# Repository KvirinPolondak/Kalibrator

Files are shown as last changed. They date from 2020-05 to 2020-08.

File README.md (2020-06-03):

# System for evaluating the color response of a digital camera sensor

A controllable light source comprising of a multiplicity of
light-emitting diodes and semiconductor lasers covering the visible
spectrum: from near infrared (1000 nm) to UVA (365 nm). The output
intensity of the diodes/lasers should be remotely controllable via USB
and/or BlueTooth. Demonstrate the use of the developed instrument to
evaluate the color gamut of at least one digital camera sensor.

# Sustav za evaluaciju odziva boje digitalne kamere

Izvor svjetla od više svjetlećih dioda i poluvodičkih lasera
koji pokrivaju vidljivi dio spektra: od 1000 nm (infracrvena boja) do
365 nm (ultraljubičasta boja A). Intenzitet svjetla iz svake diode će
se kontrolirati preko USB sučelja ili preko BlueTooth sučelja.
Demonstrirati korištenje razvijenog uređaja za mjerenje gamuta barem
jedne digitalne kamere.

## Complete documentation
https://github.com/KvirinPolondak/Kalibrator/blob/master/Dokumentacija/main_documentation.pdf

## Pictures
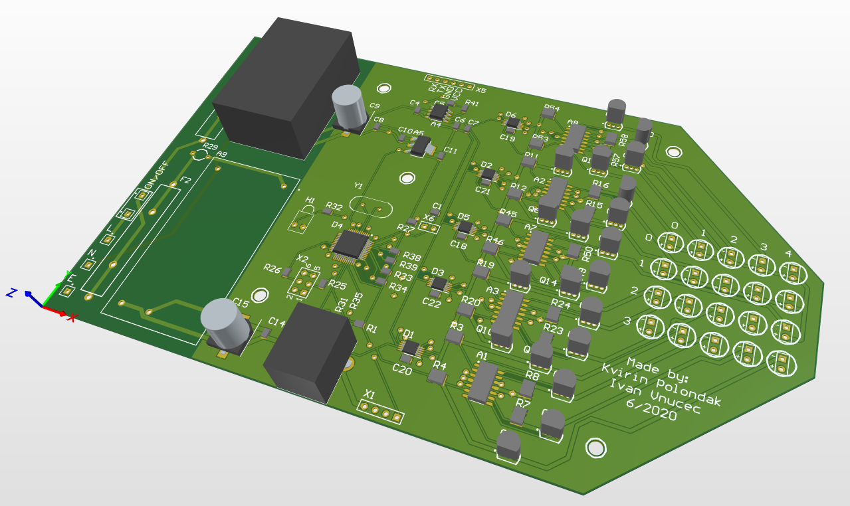
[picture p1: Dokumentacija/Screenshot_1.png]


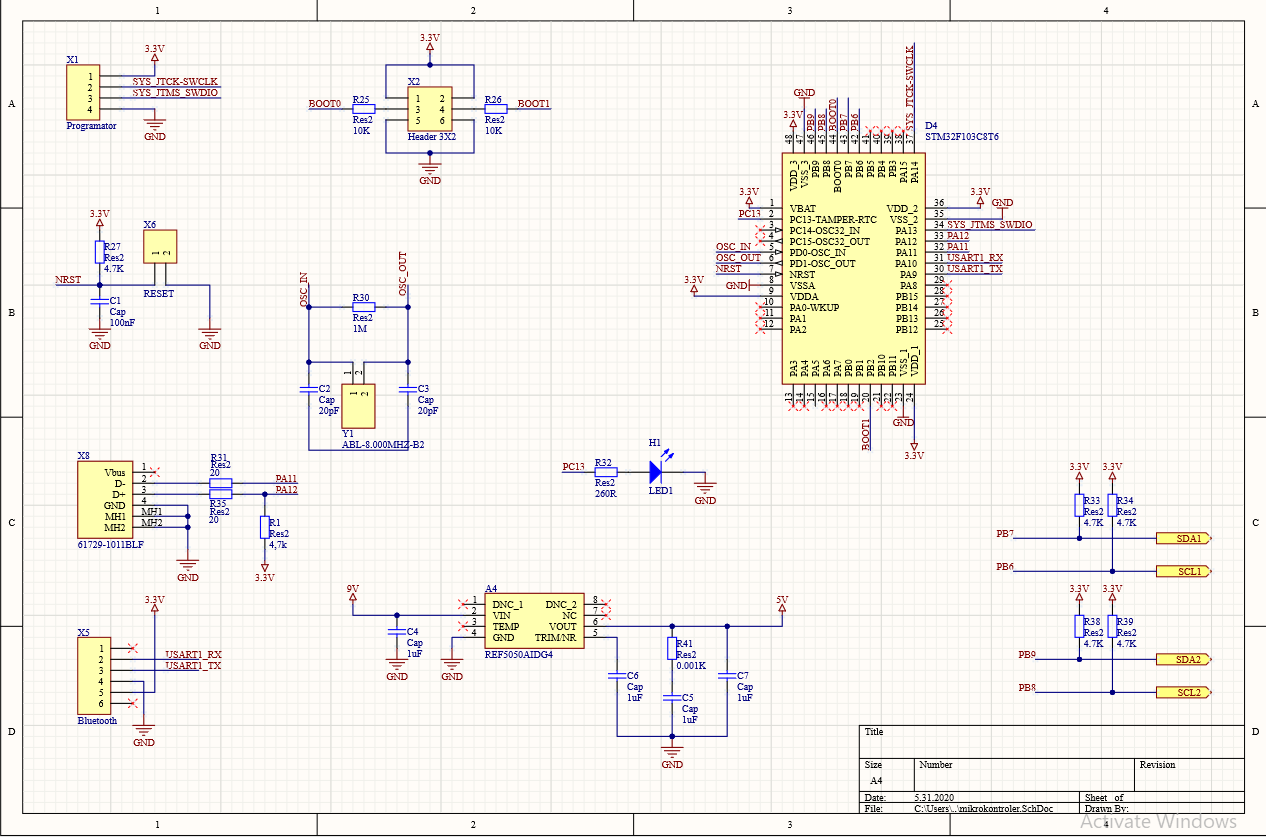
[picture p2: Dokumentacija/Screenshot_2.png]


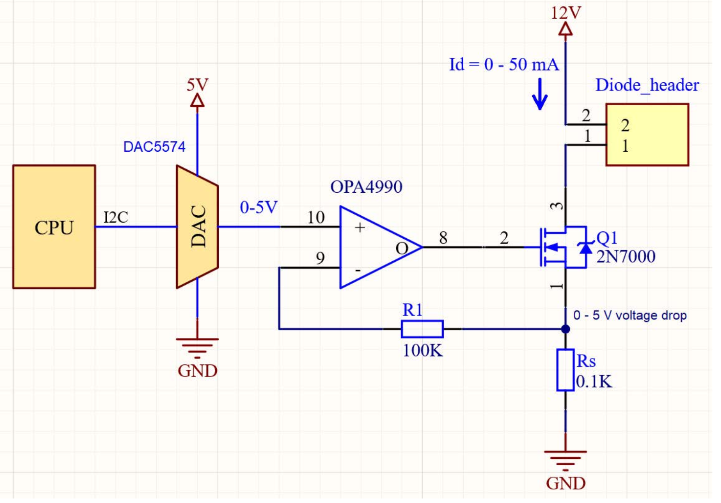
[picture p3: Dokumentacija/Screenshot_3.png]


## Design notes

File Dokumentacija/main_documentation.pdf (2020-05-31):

## Table of Contents

## Introduction

Our main goal is to distinguish various types of light sources based on their color gamut response. From the previous experiments where we had studied color gamut response from different kinds of lamps (LED, RGB LED, HPS, Fluorescent etc.) we hypothesized that we might determine the type of streetlamp only by looking at their color gamut.
Figure 1 portrays how certain kinds of lamps fall into their region and based on in what region they are in, we might decide their type.

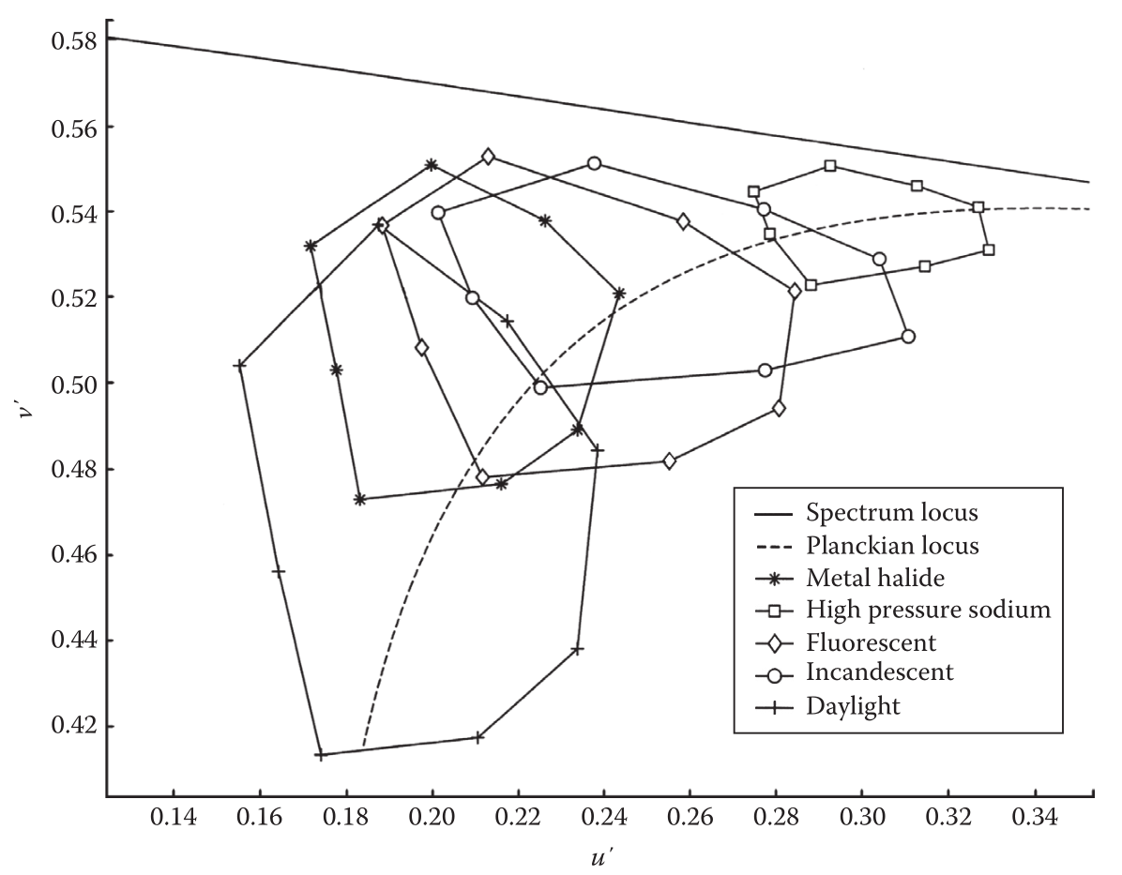
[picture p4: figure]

Figure 1 The color gamuts for high-pressure sodium (HPS), incandescent, fluorescent, and metal halide light sources, and for the CIE Standard Illuminant D65, simulating daylight, all plotted on the CIE 1976 UCS diagram. The dotted curve is the Planckian locus. (Boyce, 2014)

To test our hypothesis, firstly we would need to capture hundreds of responses from numerous light sources, which would be a tremendous job.

A method for capturing color gamut response is firstly capturing the radiating light from the light source with a digital camera and then calculate the so-called CIE chromaticity x and y and z coordinates based on the light source color. For the complete formulations, please see (Boyce, 2014).
We would like to have a device that contains numerous different monochromatic light sources. Device should turn every one of those light sources independently with user selectable light intensity.

## 1. Device

## 1.1. Requirements

Below is a list of requirements that the device must have:
- The device must contain an array of twenty two-leaded connectors to connect twenty different light sources (LEDs, Low-power lasers etc.).
- The device must have the ability to receive commands ether trough Universal Serial Bus (USB) or wirelessly with the Bluetooth protocol. Commands must be in a simple ASCII string form.
- Every command must specify what light source should be turned on and with what intensity.
- The board must be powered with conventional EU plug (230V, 60 Hz).

## 1.2. Principle of operation

Figure 2 portrays general functional block diagram. On the left side we have two communication ports: USB and Bluetooth. Both of those communication channels are bidirectional.
Between a communication ports and light-sources-array lays low-cost general-purpose microcontroller that acts as a bridge between the two. His function is to encode the user commands (which are human readable) into analog voltage and current that would drive each light-source.
Next to the microcontroller is light-source-array consisting of 20 different monochromatic light-sources. Every different light-source is physically swappable by the user.

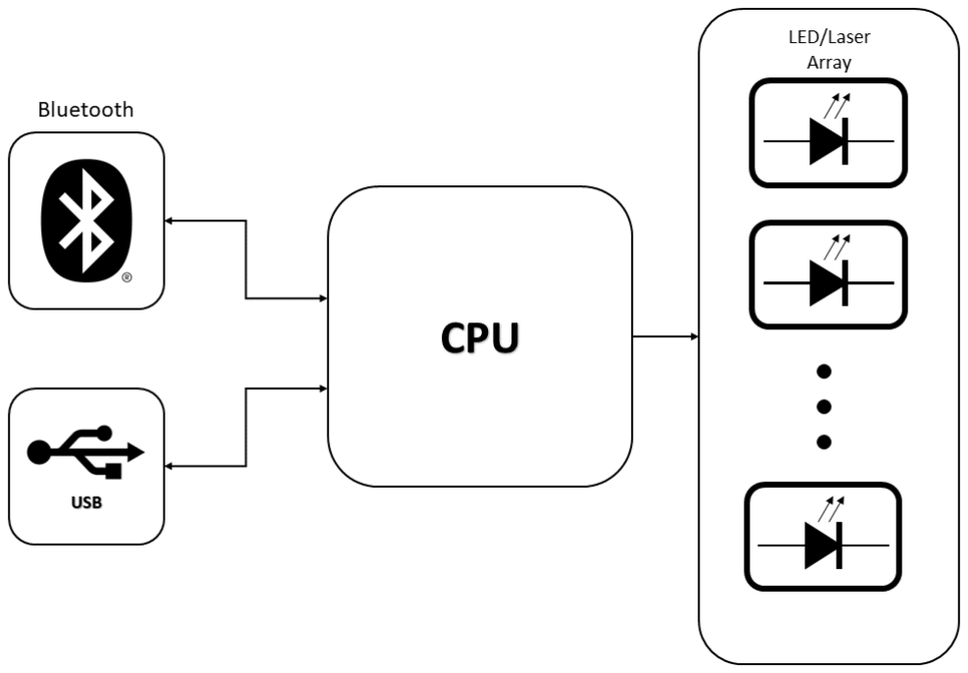
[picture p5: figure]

Figure 2 - Functional block diagram

### 1.2.1. Communication

### Bluetooth

Bluetooth stack and communication protocol is vast topic by its own. As a result, we have chosen a system-on-chip solution (SOC) Bluetooth module. The module has the advantage over other Bluetooth solutions because the communication between two Bluetooth nodes goes over a UART protocol with an ASCII coded characters as data.
We intend to use rather famous between hobbyists AT-09 module. Other modules could also be of good use as long as they have the simple UART interface.

### USB

For the USB side it is no different. Microcontroller has native support (both hardware and software) for USB communication. Data will be sent through established Virtual COM port emulation RS-232 serial communication in ASCII decoded characters.

### 1.2.2. CPU

For the CPU we chose general-purpose STM32F103 series microcontroller (MCU), which has all the functionalities we need: USB, USART, and two I²
C communication ports. Also, contains 64 KB Flash memory and 20 KB RAM, which is sufficient for our application (STMicroelectronics , 2020).

### Functionality

The MCU receives commands through USB or Bluetooth, encodes them, and then sends them to the Light source array over I²
C communication. The latter part is explained later in details.

### 1.2.3. Light-source array

### Overview

Figure 3 portrays the light-source array consisting of 20 independent LED or laser diodes where each light-source can be lit with its own amount of current.
The array consists of modules where every single module has analog circuitry that governs an amount of current and voltage of each diode.

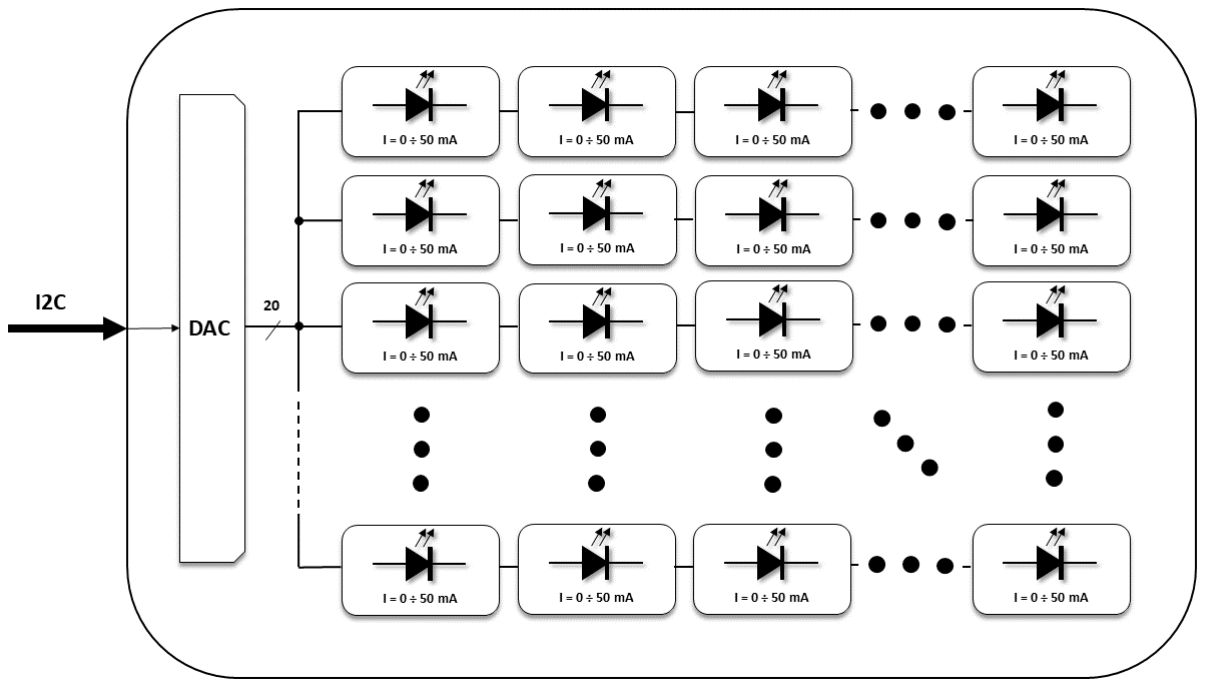
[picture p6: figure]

Figure 3 - Light-source array

Every cell consists of one Digital-to-analog converter (DAC), Operational amplifier (OP-AMP), MOSFET transistor, current-sense resistor, and one header connector for the diode (Figure 4).

### Principle of operation

Id is the desired current trough the diode ranging from 0 to 50 mA. This current creates voltage drop on the current-sense resistor Rs in the range from 0 to 5 volts. This voltage drop then goes to the OP-AMP which then compares the desired voltage (+ side) to the voltage drop across Rs resistor. The DAC output voltage ranges also from 0 to 5 volts. Based on the difference, OP-AMP drives the gate of the MOSFET which then regulates the current trough the diode by varying its drain-to-source voltage drop.

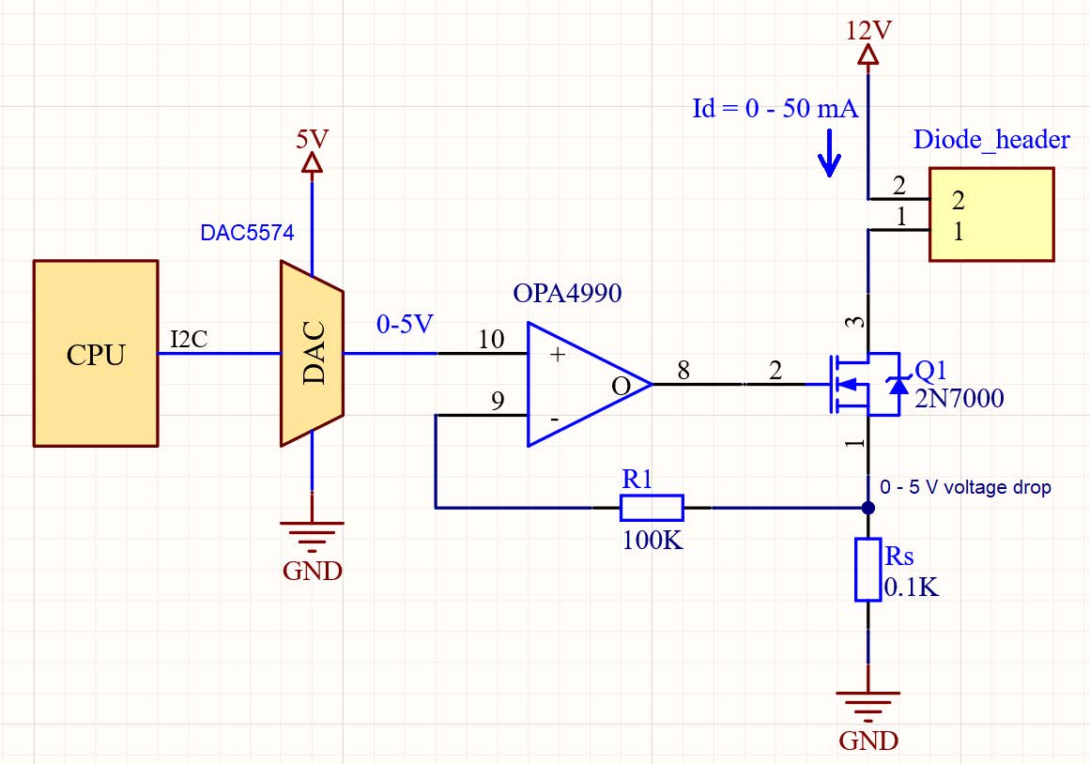
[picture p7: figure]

Figure 4 - Light-source array cell

DAC

The DAC5574 is a rail-to-rail, quad channel, 8-bit digital-to-analog converter (DAC) whose output voltage ranges from 0 to 5 volts. It consists of 4 DACs in one package in order to save printed-circuit board (PCB) space.

Least significant bit (LSB) of the DAC output is equivalent to:

# ULSB = Uout

# 2n_bits = 5 V

# 256 bit

≅ 19.531

mV
bit .

Communication with the DACs goes over an I

2
C interface.

OP-AMP

For the OP-AMP, we chose OPA4990 general-purpose operational amplifier with rail-torail input/output. It consists of 4 OP-AMPs in one package in order to save PCB space. The OP-AMP output is directly connected to a 2N7000 gate general-purpose, low-voltage, enhanced-mode MOSFET.
The OP-AMP short-circuit-input principle gives us the LSB diode current:

# Id,LSB = ULSB

Rs

≅

19.531 mV

### bit

100 Ω

≅ 0.1953

mA
bit .

Therefore, with the 8-bit DAC output we have 0-50 mA current swing.

MOSFET

General-purpose 2N7000 MOSFET drives its drain-to-source voltage drop in order to set a desired current trough the diode specified by the OP-AMP.
Because of the low power-loss across the transistor, we have chosen TO-92 package.

Power supply voltage

We chose 12 Volts as the power supply voltage because it covers wide forward-voltagedrop range.

## 2. Usage

This section describes general procedures of using the device.

## 2.1. Power

Power supply

In order to power up the device, user must plug in main power plug into 230 V, 50 Hz EU electrical socket and then turn on the main power switch.
If there are no errors, the status LED should be blinking and the light-source array is completely turned off.

Fuses

To prevent the device from permanent electric damage user must install two different fuses. To install fuses user should firstly power off the device by unplugging it from the electrical grid and then open the box.
Into designated fuse holders, install two types of fuses:
- Slow blow, 40 A, 250 V for 12 V rail and,
- Slow blow, 20 A, 250 V for 9 V rail.

## 2.2. Light-source array

In order to place individual light sources, firstly turn the device off. Next, put two leads into their appropriate header paying attention about leads polarity.
After plugging the device on, the light-source array is automatically entirely turned off.

## 2.3. Communication

### USB

In order to use USB communication, user should connect PC and a device with an USB 2.0 type B connector cable.
The device should appear on a PC as a virtual COM port. Communication with the device can be established via standard Serial port monitors.

### Bluetooth

To use Bluetooth communication user must firstly establish a connection between two Bluetooth devices. After that, user should use standard Serial port monitors. Serial port monitors exist for both PC and mobile phones.

### Commands

Commands could be sent using traditional Serial port monitors with a simple commands format explained below.

### Commands format

In order to address every single light source, we have developed a command format which every user must follow. The format is explained below:
D_XX_YY.ZZ
Where:
- “D” is an ASCII character abbreviating the word diode,
- “XX” is a leading zero, two digit, natural number (e.g., 00, 01, 02 , … , 98 ,
99) representing a diode ID and
- YY.ZZ is a leading zero, rational number (e.g., 00.00 , 00.01, … , 99.99) representing a current trough the light source in miliamperes (see Light-source array heading).
For example, if user wants to set a 3.52 mA current trough some arbitrary diode with an ID No. 7, user must send an ASCII command string:

D_07_03.52
Highest YY.ZZ diode current is 50.00 miliamperes by design. If user sends command with a higher current requirement, the command will be ignored. In order to turn off the diode, user should put 00.00 as the YY.ZZ value.
Diode ID numeration is shown in figure below. First ID (00) is in phisicly located in the upper-left corner. Next ID (01) is located next to it to the right side and so on.

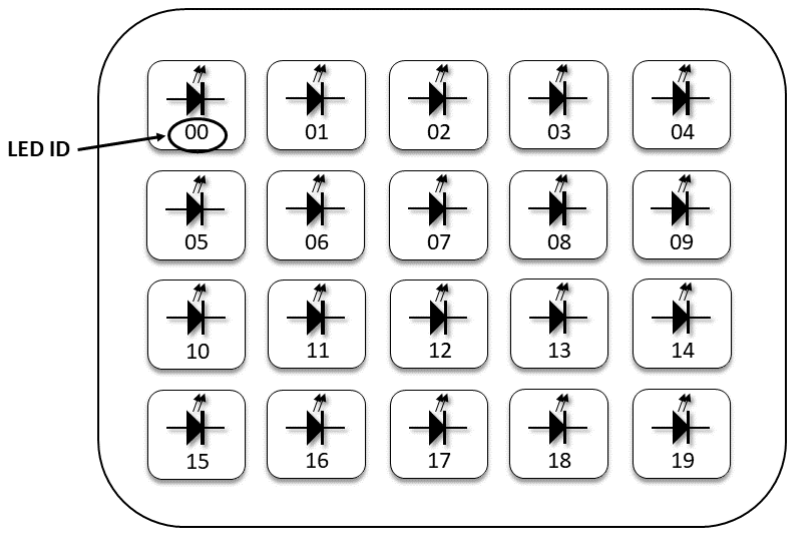
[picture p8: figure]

Figure 5 - Physical layout of the light-source array

## Conclusion

asdasdsd

## Literature

Boyce, P. R. (2014). Human Factors in Lighting. Boca Raton: CRC Press. STMicroelectronics . (7. May 2020). STMicroelectronics . Preuzeto 7. May 2020 iz Microcontrollers & Microprocessors: https://www.st.com/en/microcontrollersmicroprocessors/stm32f103.html
Texas Instruments. (n.d.). Product page. Preuzeto May 2020 iz DAC5574 product page: http://www.ti.com/product/DAC5574
Texas Instruments. (n.d.). Products. Preuzeto May 2020 iz OPA4990 product page: https://www.ti.com/product/OPA4990

## Abstract

System for evaluating the color response of a digital camera sensor
Build a controllable light source comprising of a multiplicity of light-emitting diodes and semiconductor lasers covering the visible spectrum: from near infrared (1000 nm) to UVA (365 nm). The output intensity of the diodes/lasers should be remotely controllable via USB and/or Bluetooth. Demonstrate the use of the developed instrument to evaluate the color gamut of at least one digital camera sensor.

## Sažetak (Croatian)

Sustav za evaluaciju odziva boje digitalne kamere
Izraditi izvor svjetla od više svjetlećih dioda i poluvodičkih lasera koji pokrivaju vidljivi dio spektra: od 1000 nm (infracrvena boja) do 365 nm (ultraljubičasta boja A). Intenzitet svjetla iz svake diode će se kontrolirati preko USB sučelja ili preko Bluetooth sučelja. Demonstrirati korištenje razvijenog uređaja za mjerenje gamuta barem jedne digitalne kamere.

## Keywords

Ovo poglavlje nije obavezno, ali se može dodati radi preglednosti.

ATM Asynchronous Transfer Mode | asinkroni način prijenosa
ISDN Integrated Services Digital Network | digitalna mreža integriranih usluga

Napomena: na naslov Skraćenice primijenite stil Heading 1, a zatim ručno maknite brojčanu oznaku (to je važno kako bi i skraćenice ušle u sadržaj na početku rada, prije uvoda). Pri kreiranju popisa skraćenica koristite stil nabrajanje.

## Appendix A: PCB documentation

## A.1 Schematic sheet documents

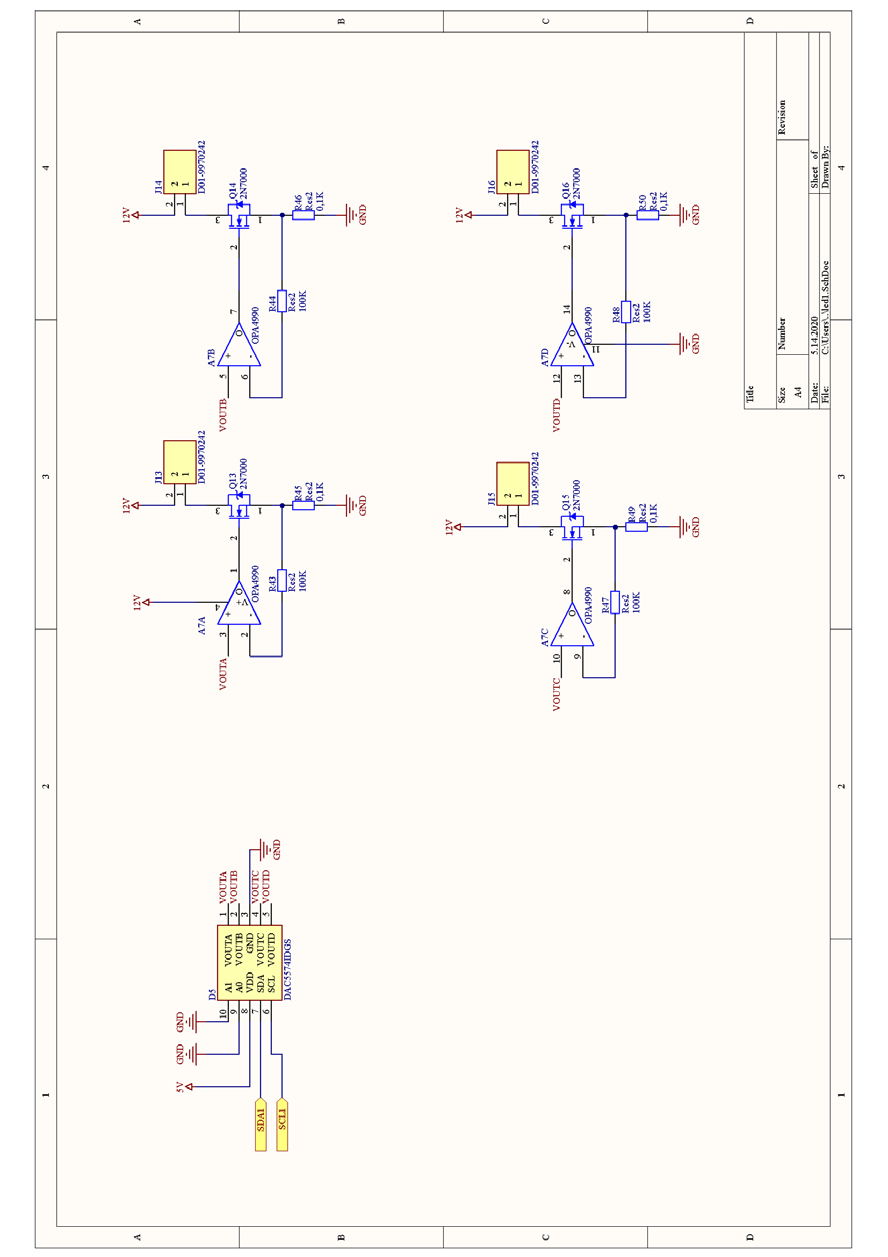
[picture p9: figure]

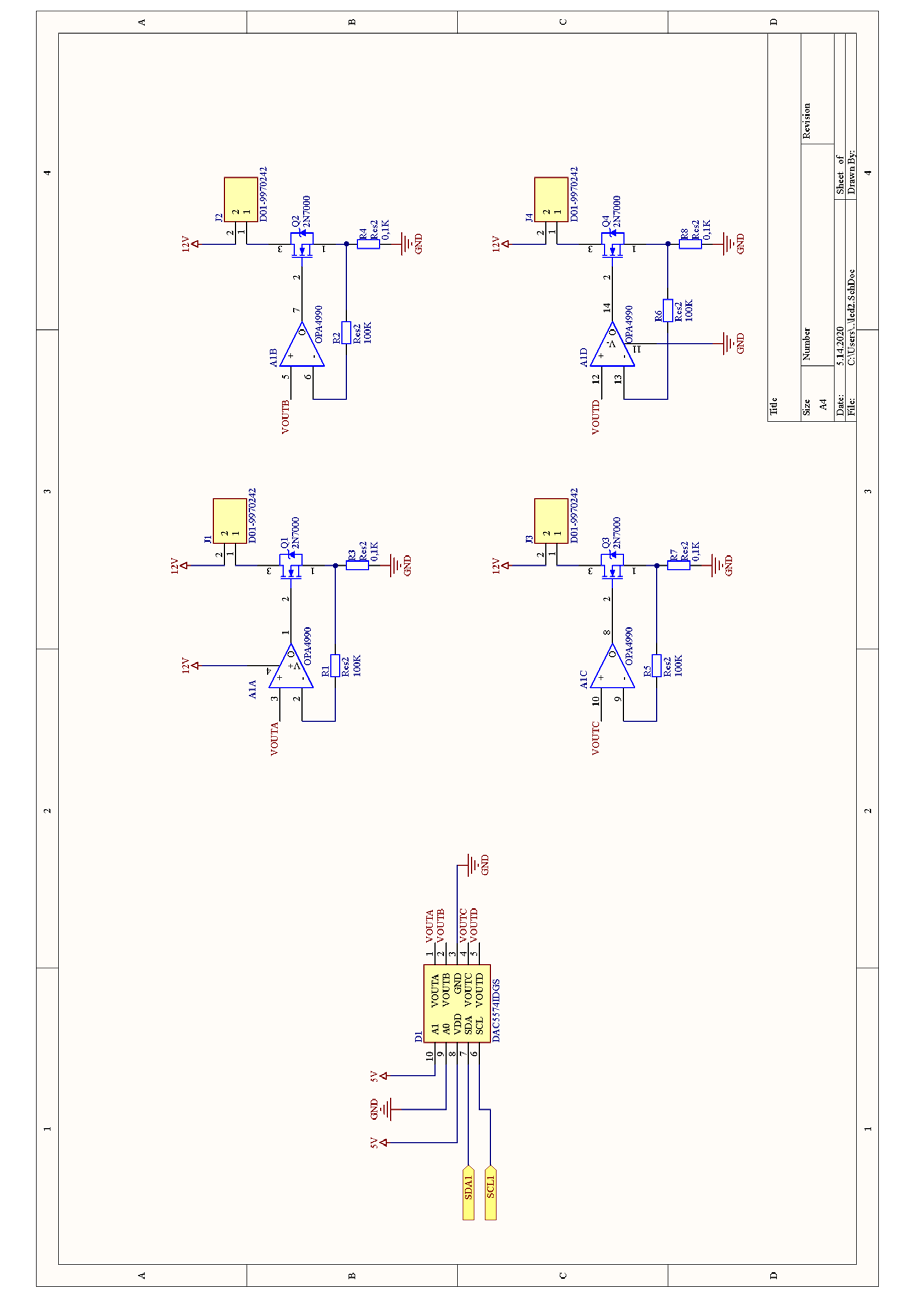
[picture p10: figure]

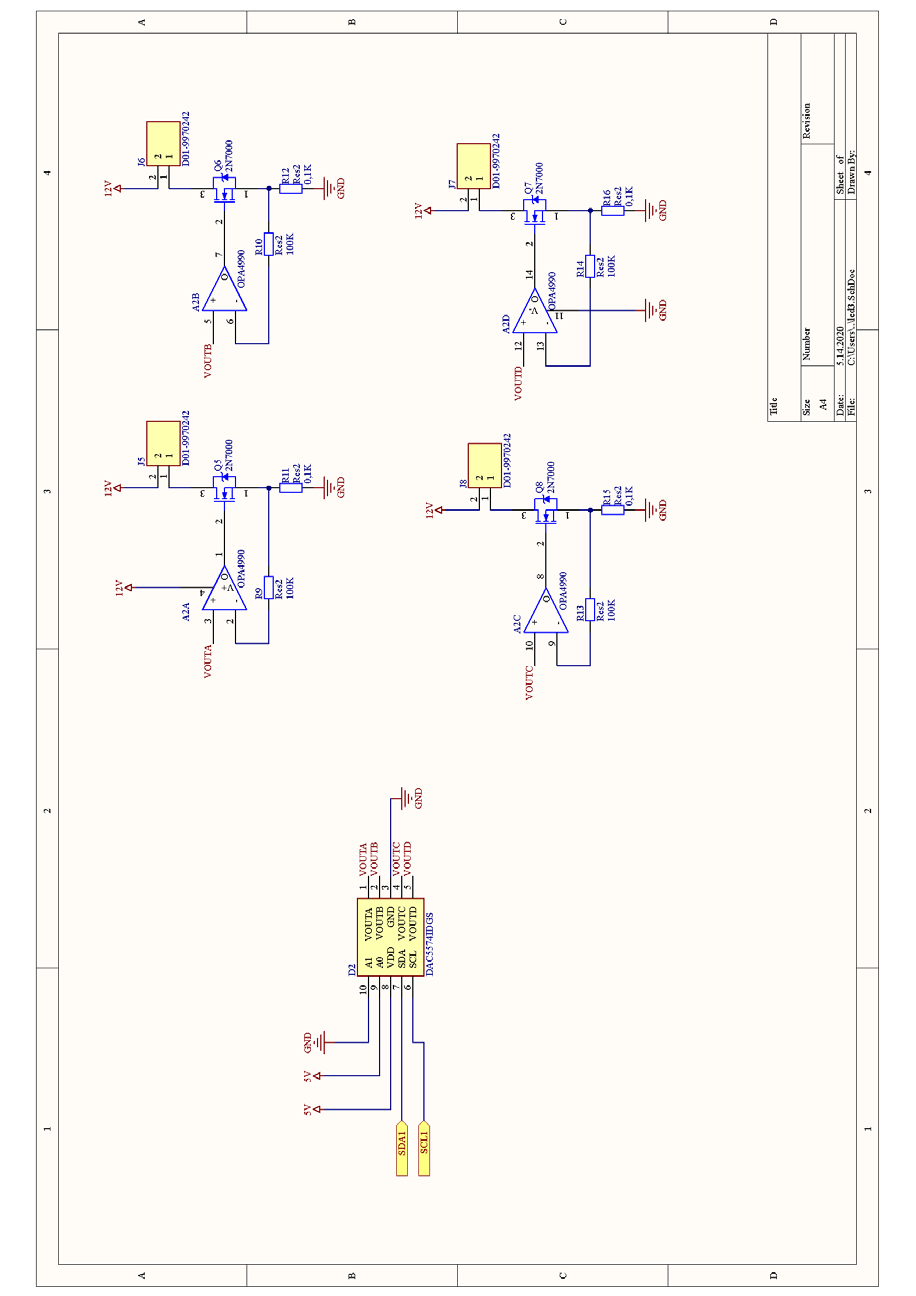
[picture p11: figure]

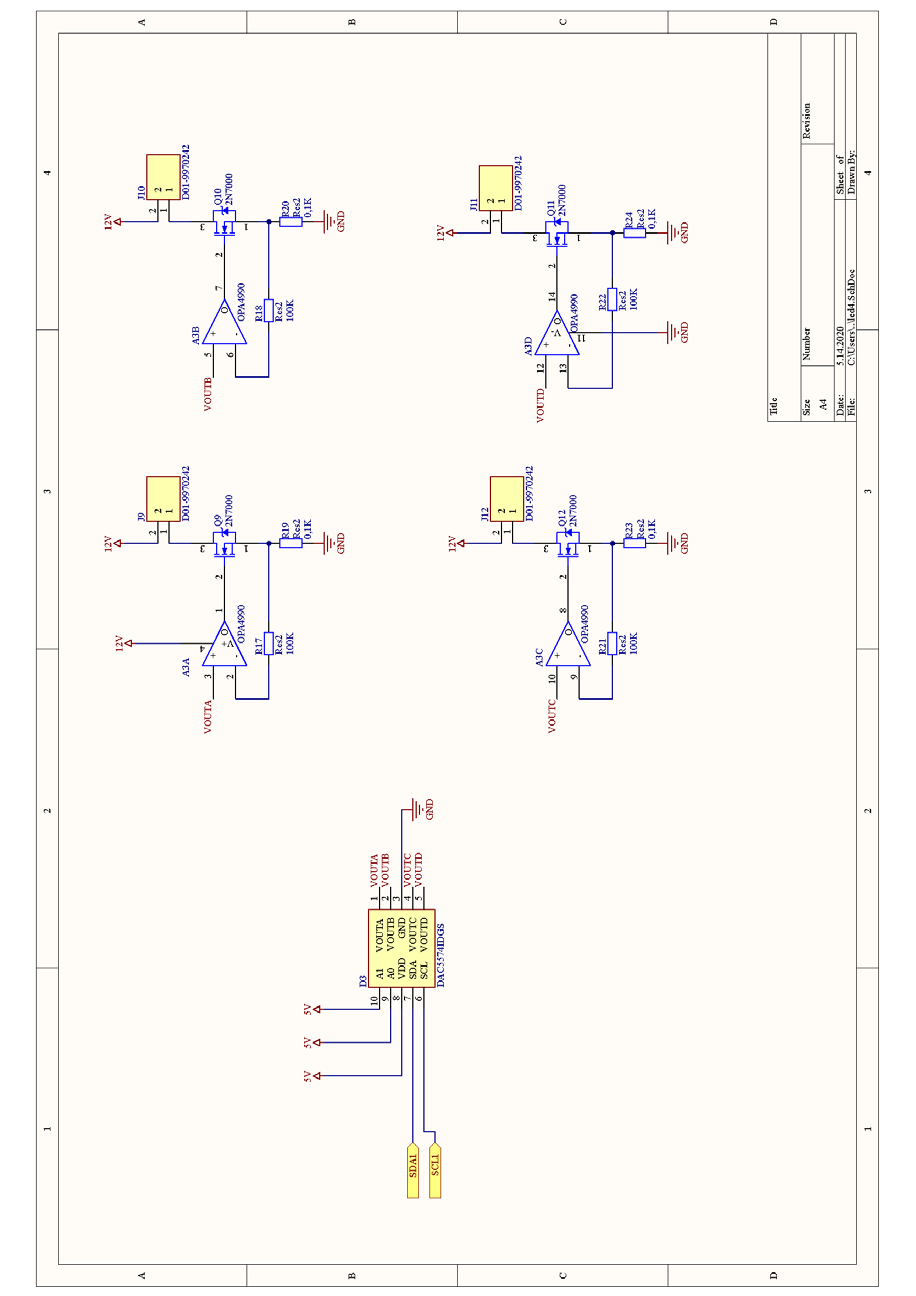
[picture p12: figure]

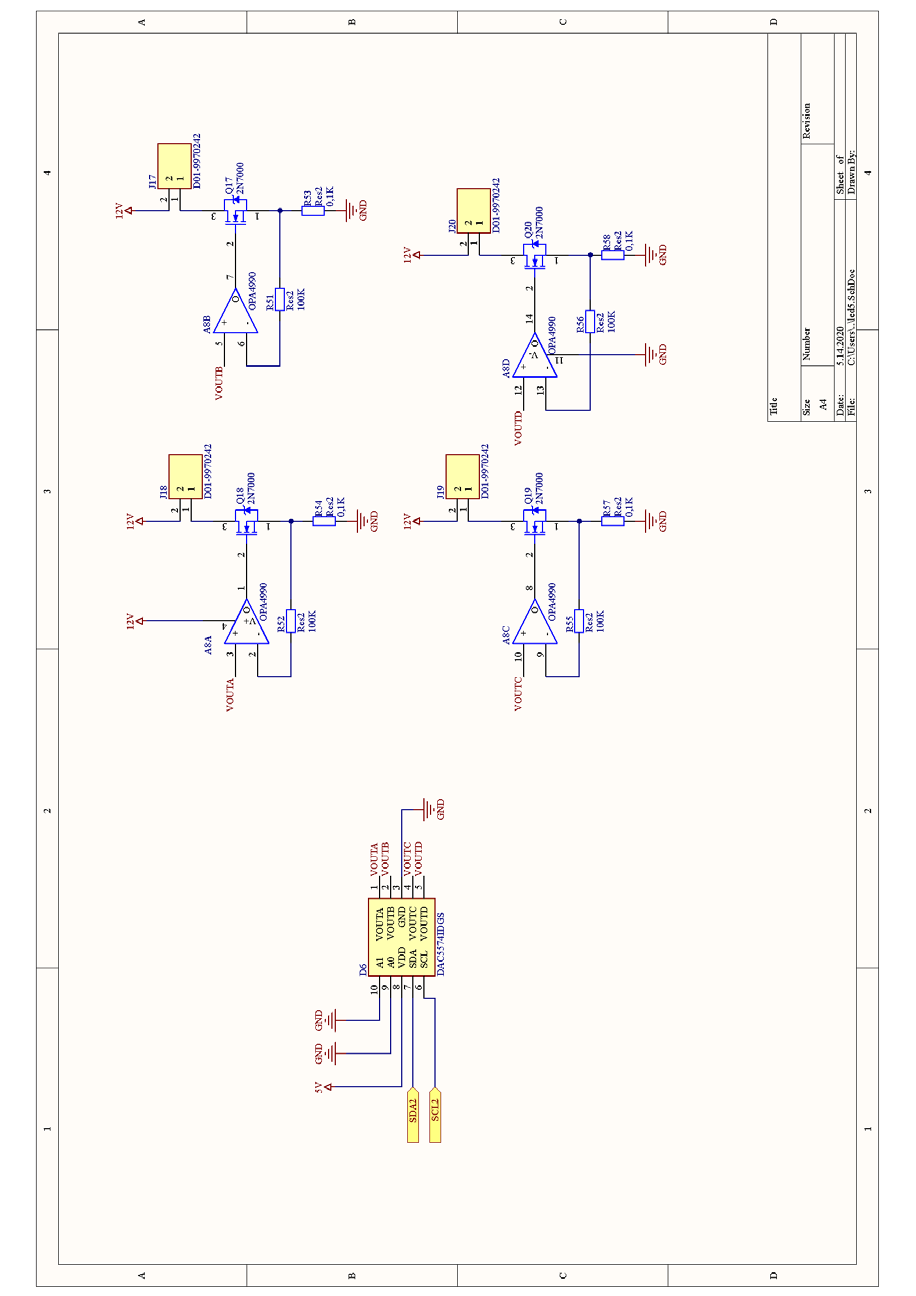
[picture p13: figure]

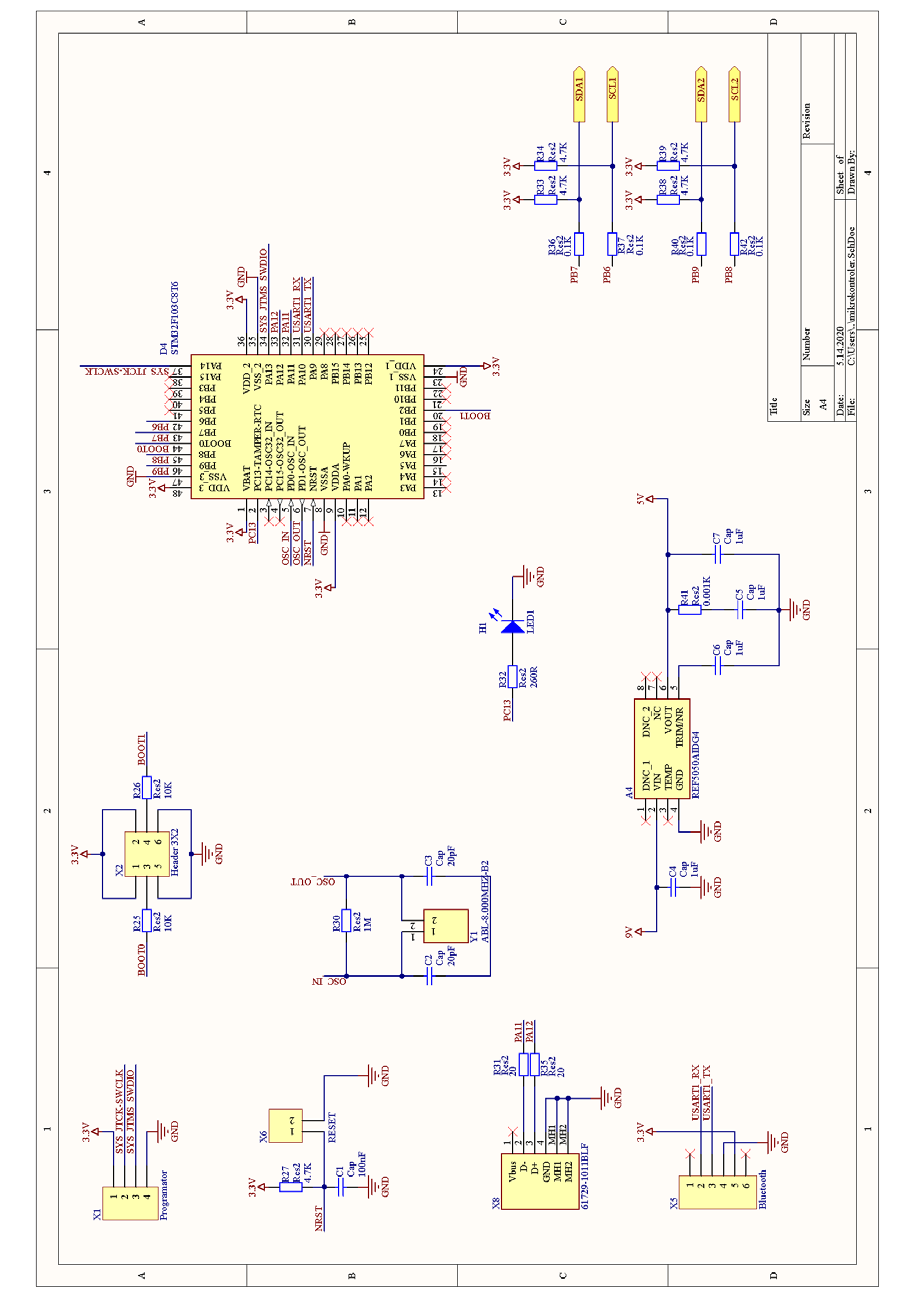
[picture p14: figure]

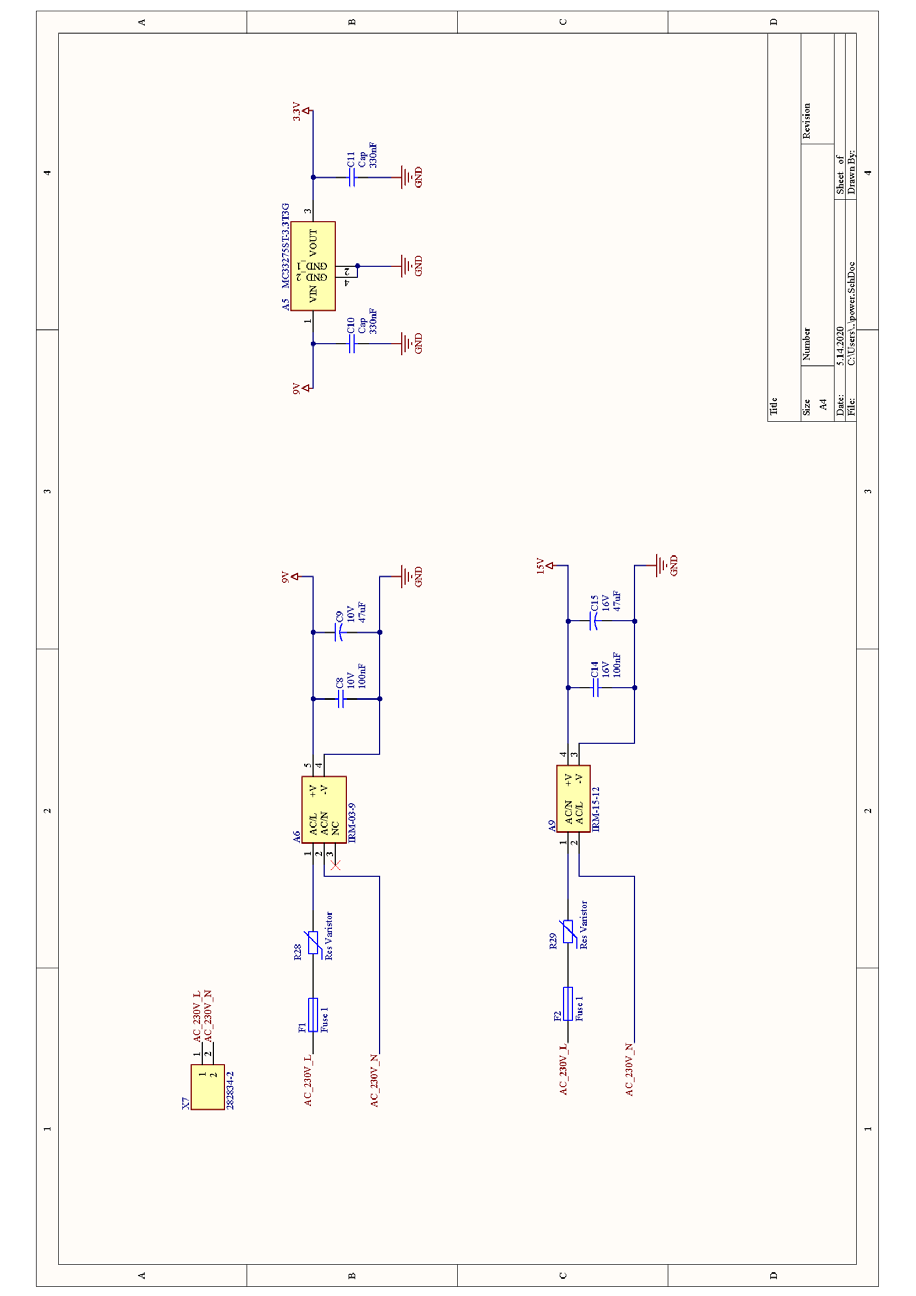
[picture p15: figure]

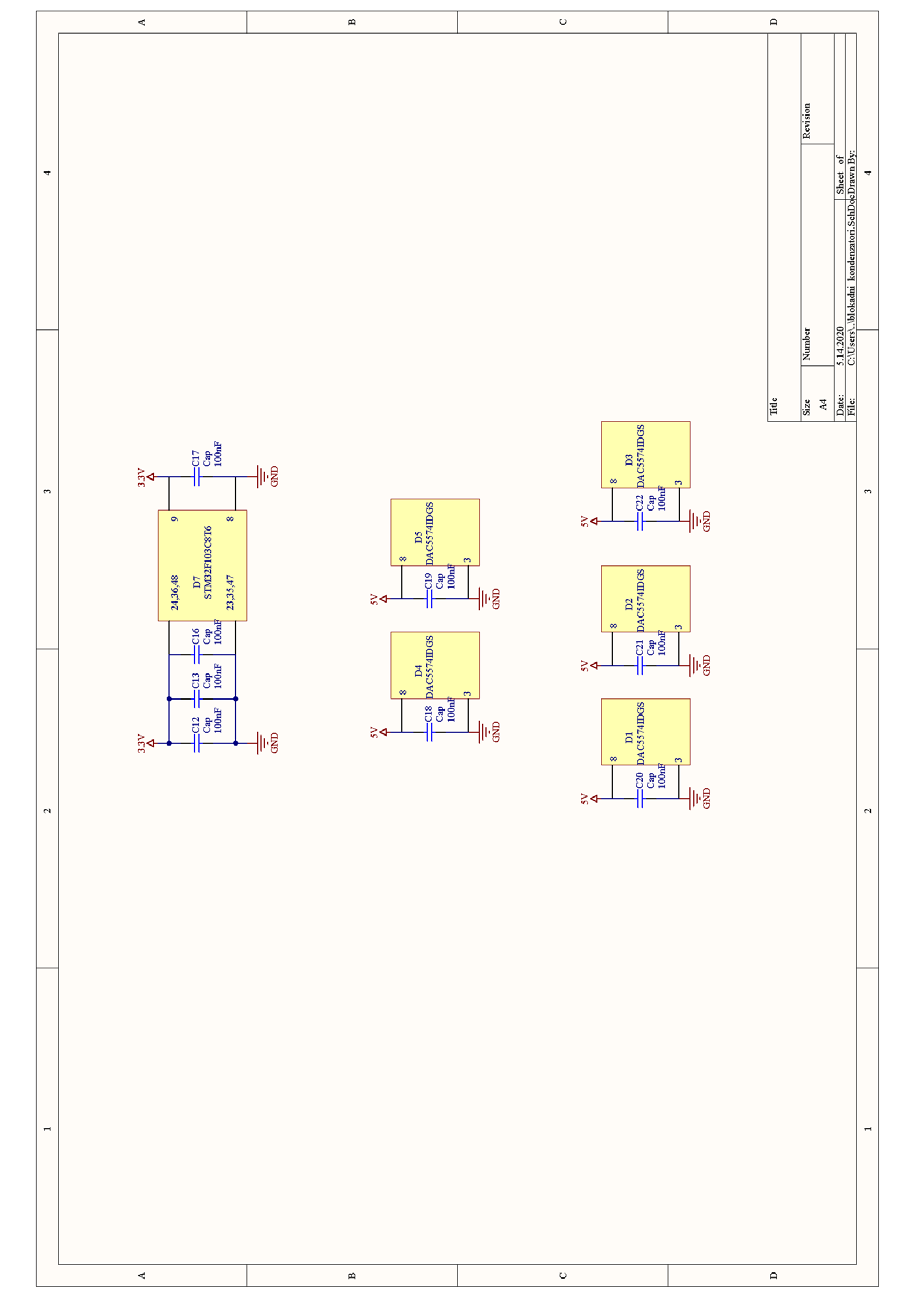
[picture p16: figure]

## A.2 PCB layout

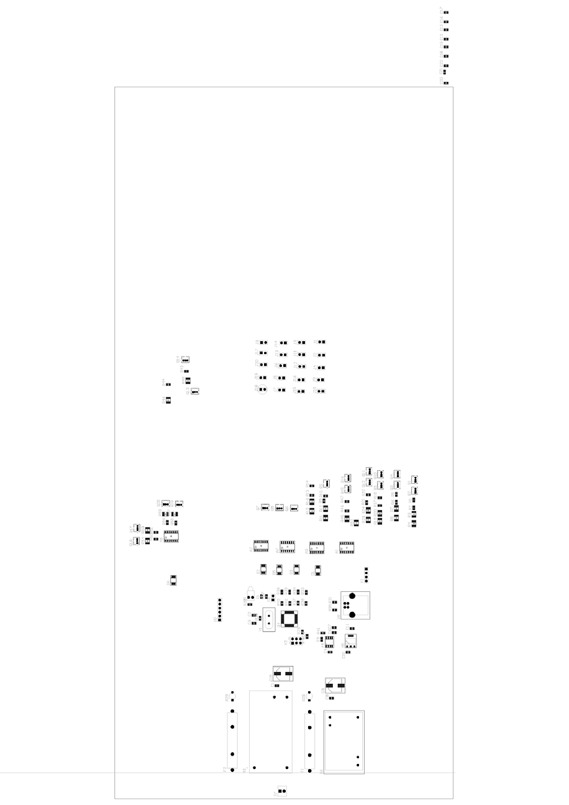
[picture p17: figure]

## Appendix B: Datasheets

## B.1 STM32F103C8T6 microcontroller

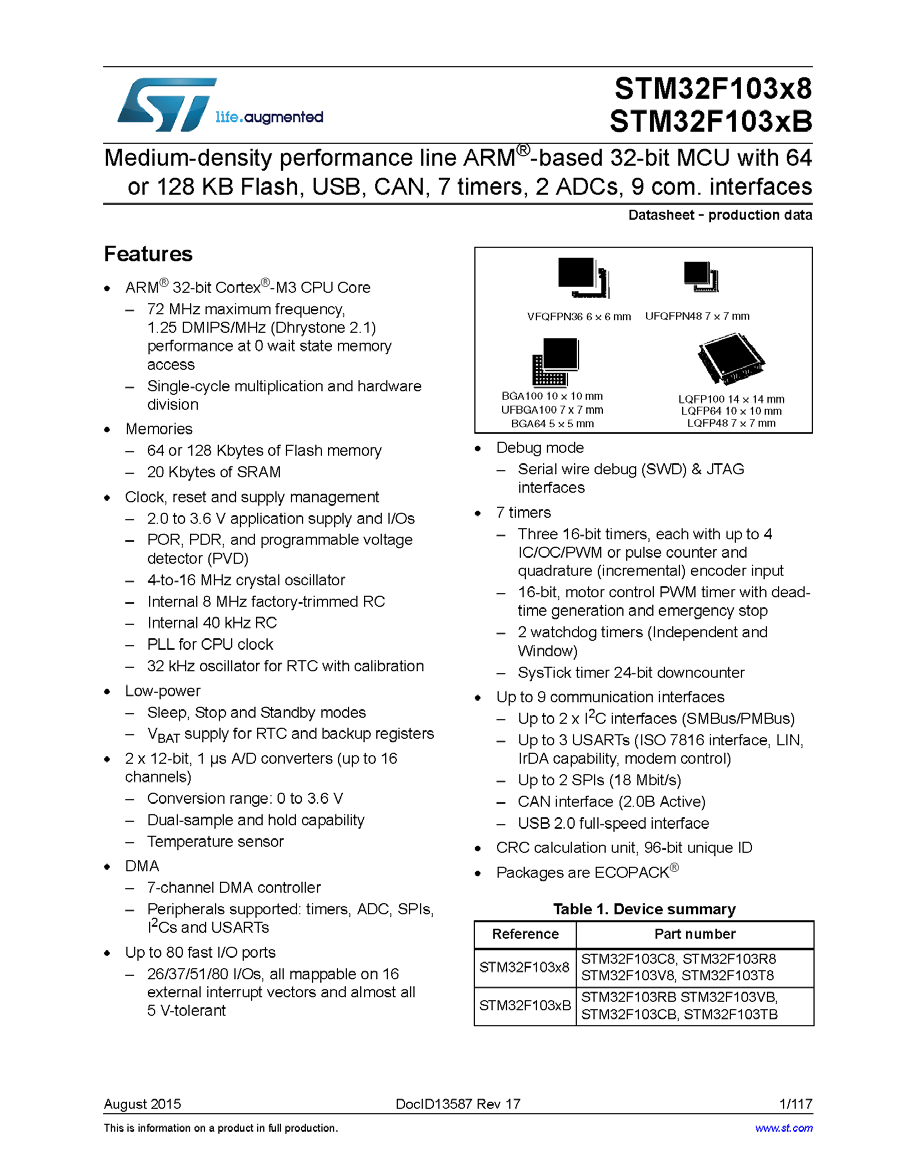
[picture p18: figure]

## B.2 DAC5574 DAC

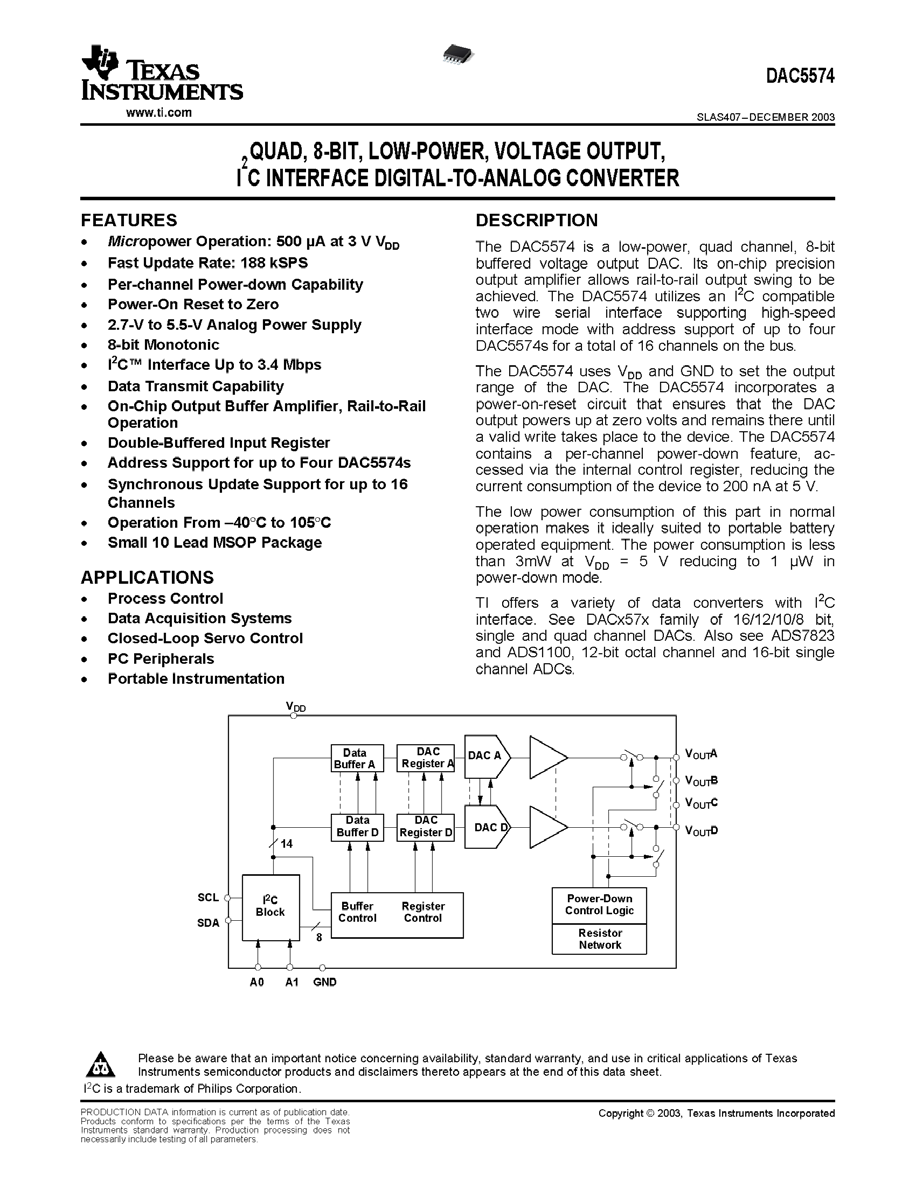
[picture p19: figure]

## B.3 OPA4490 OP-AMP

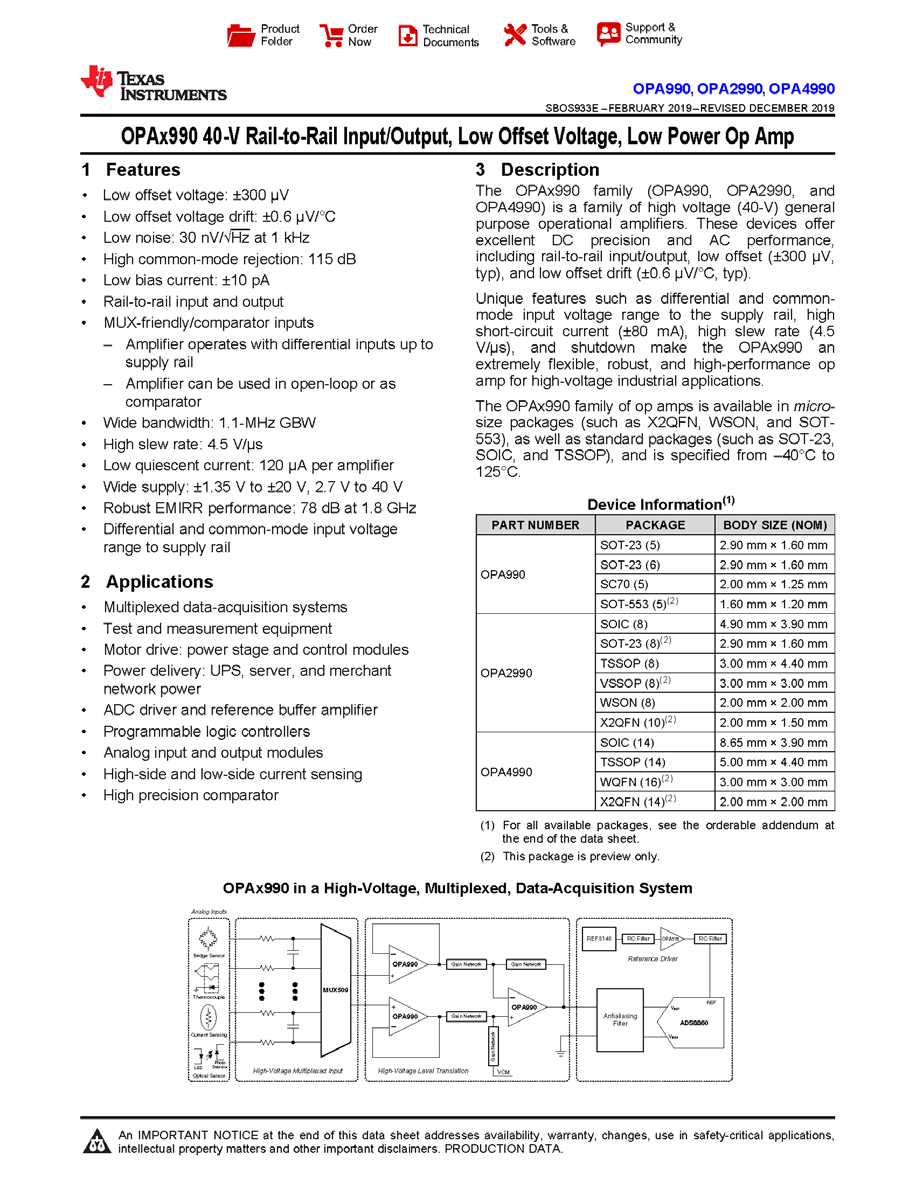
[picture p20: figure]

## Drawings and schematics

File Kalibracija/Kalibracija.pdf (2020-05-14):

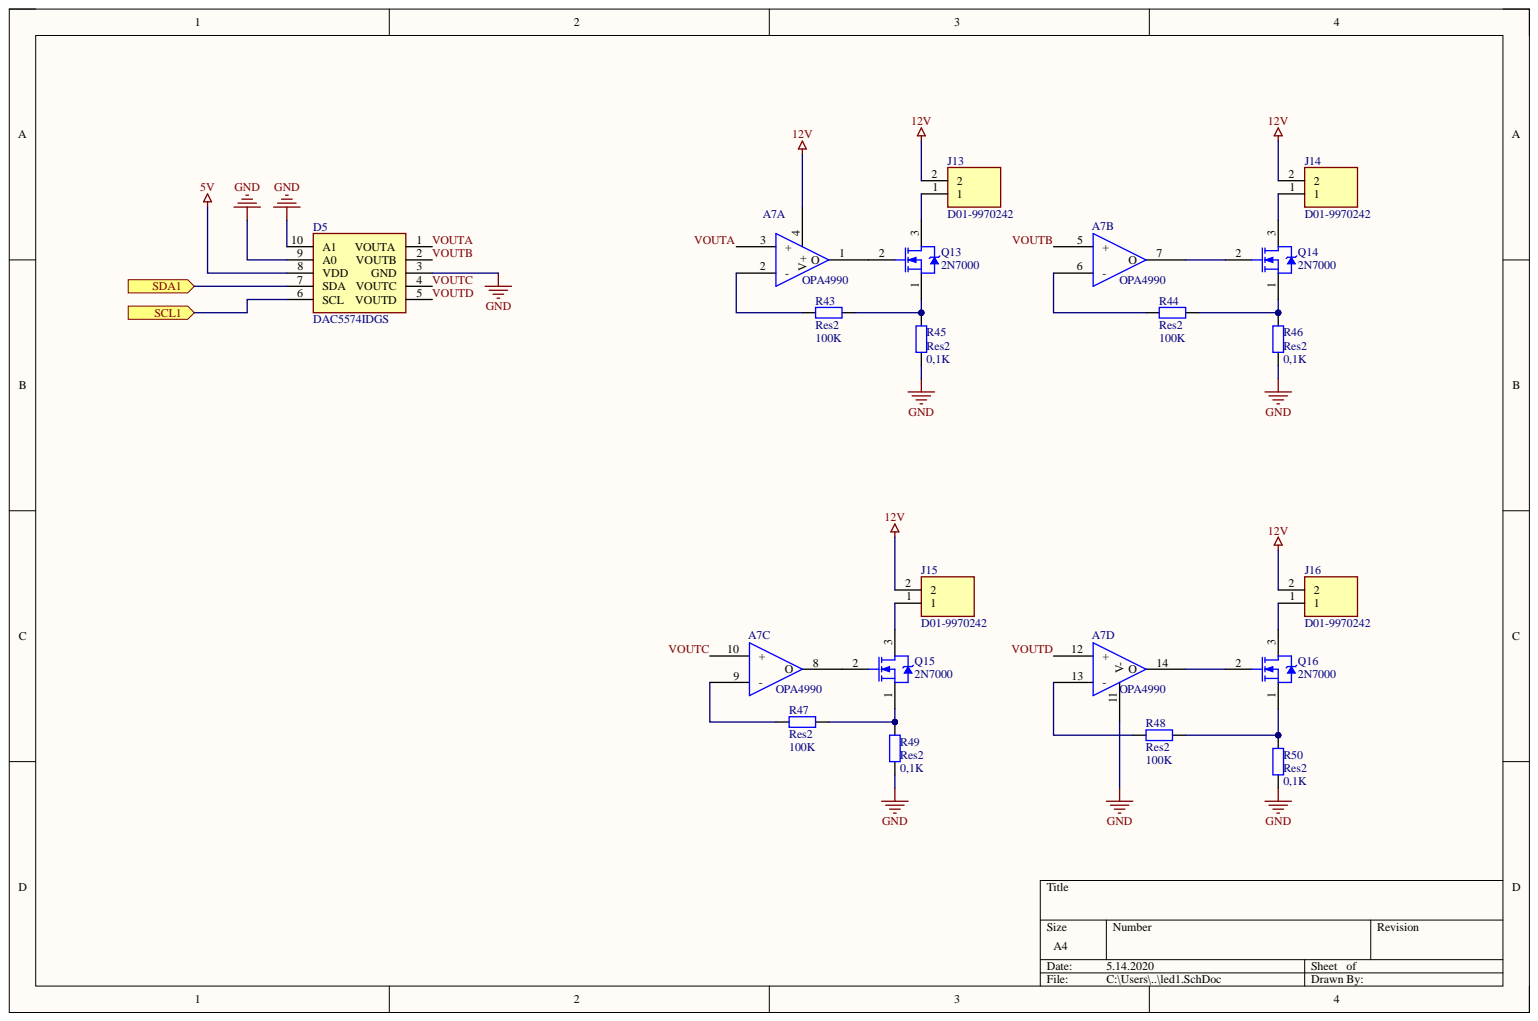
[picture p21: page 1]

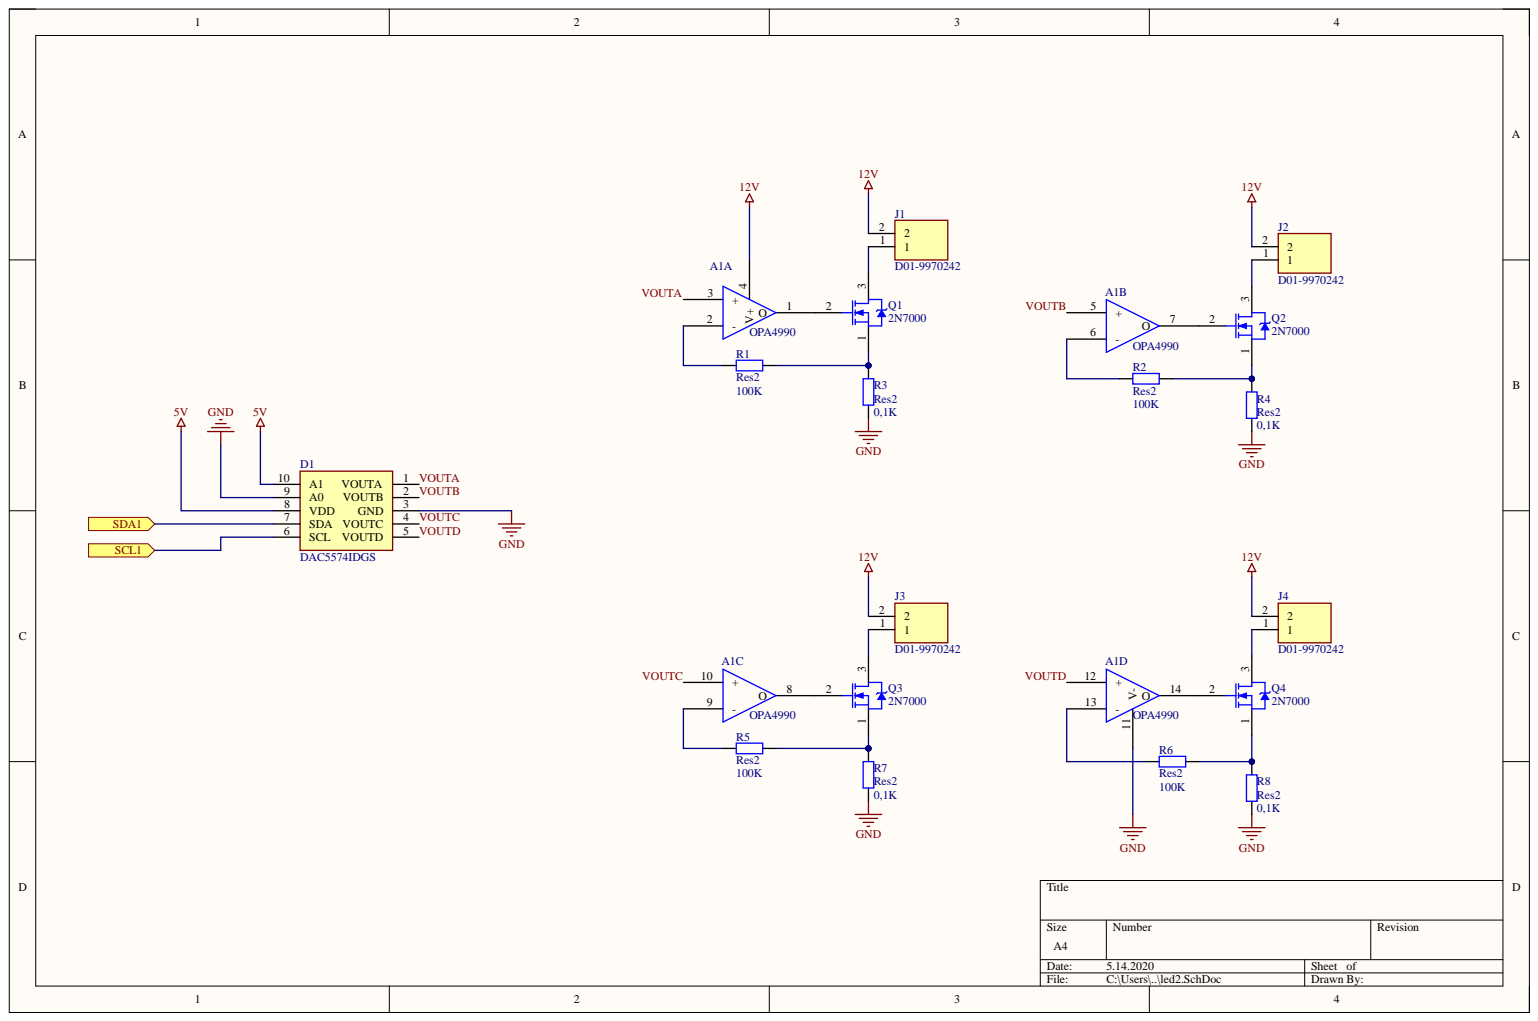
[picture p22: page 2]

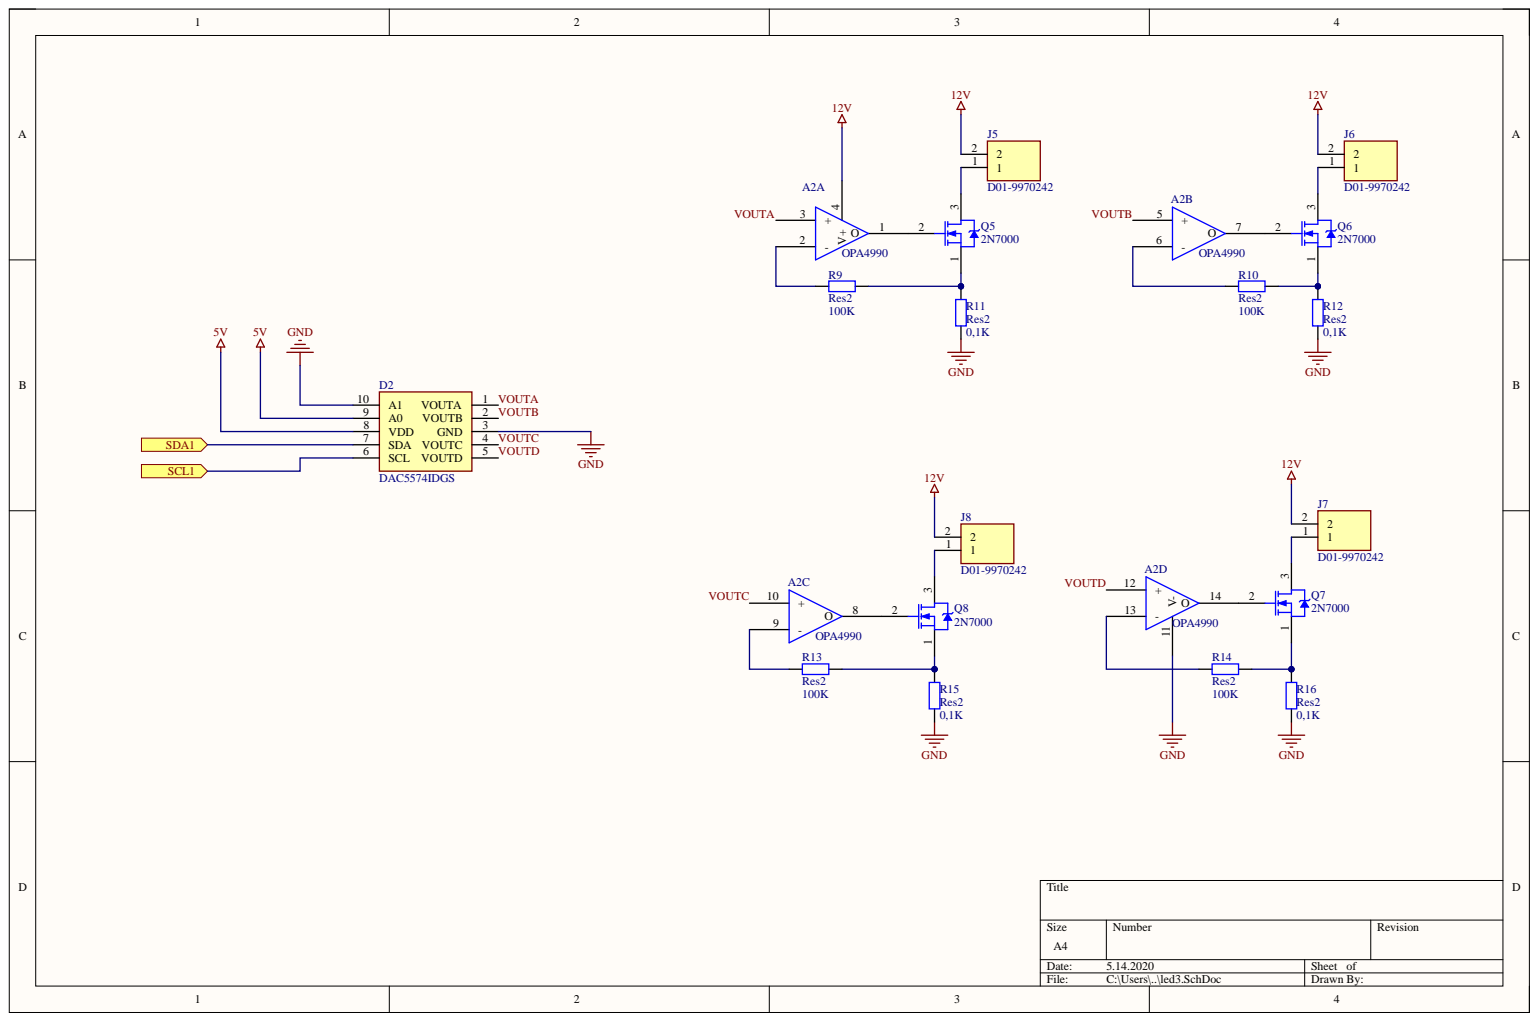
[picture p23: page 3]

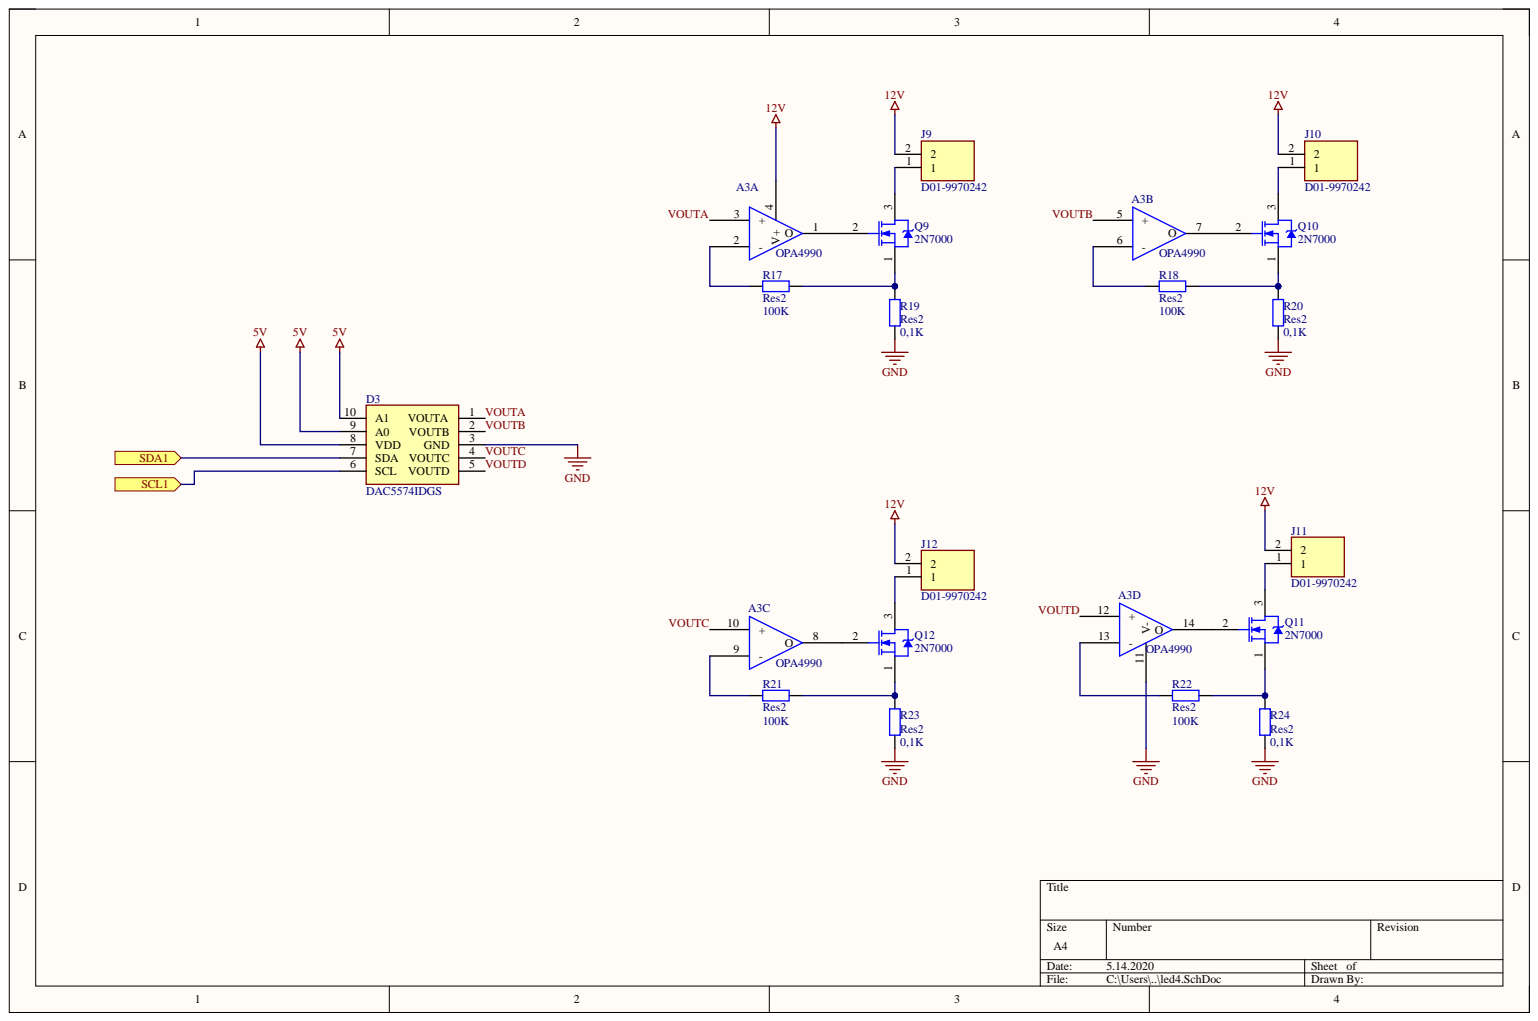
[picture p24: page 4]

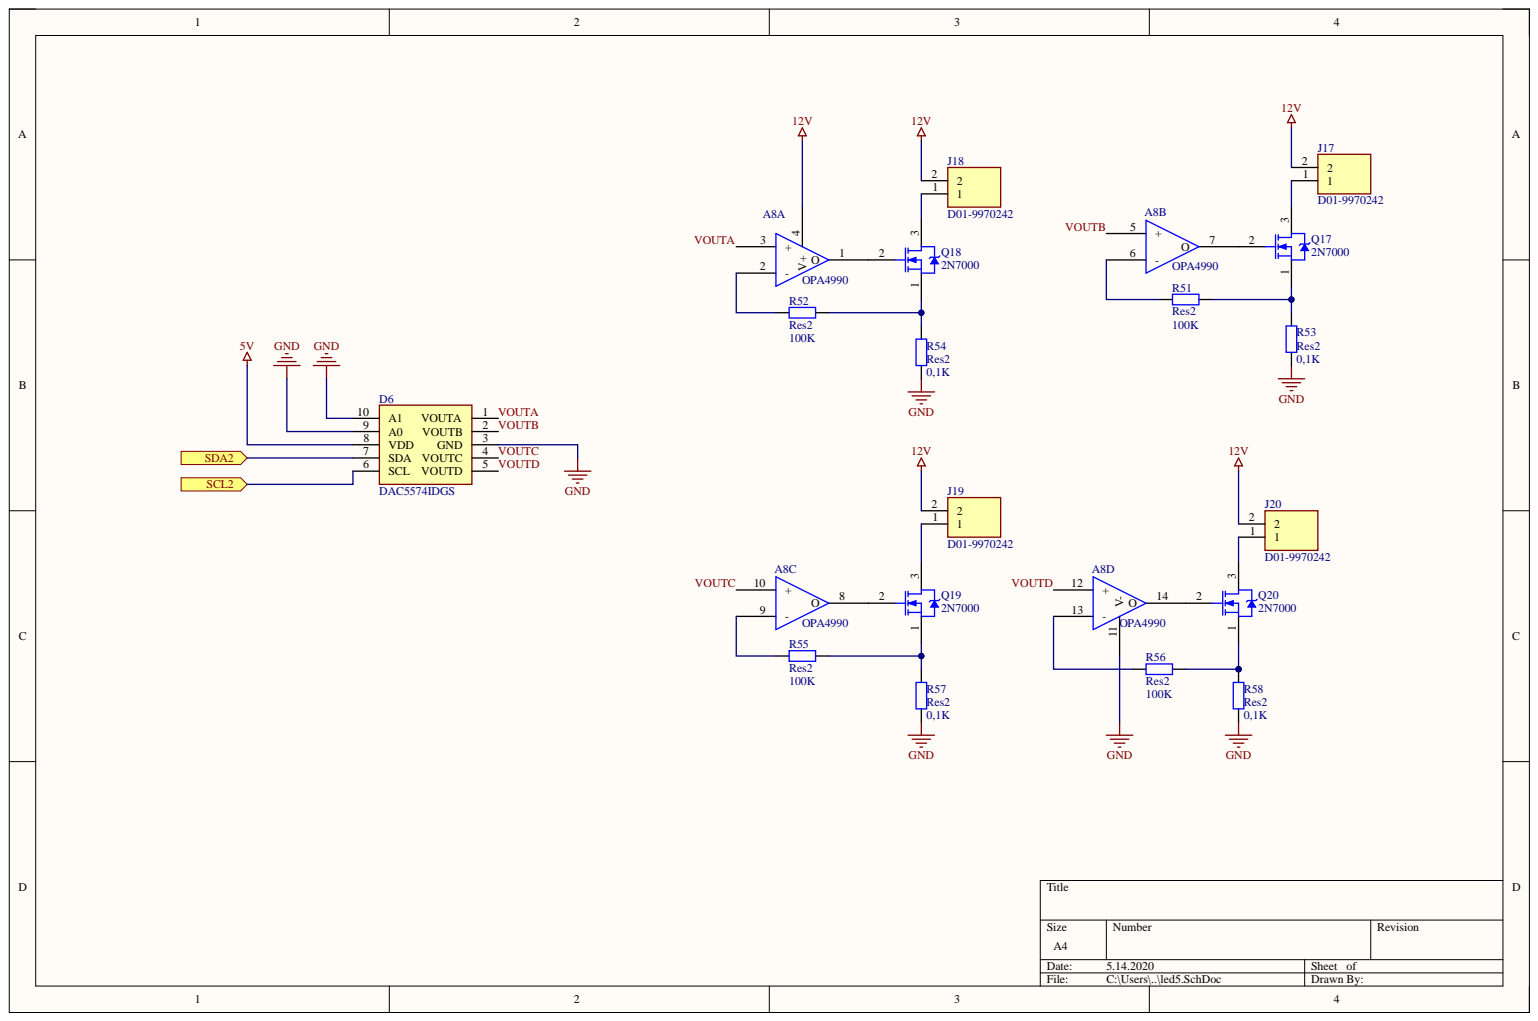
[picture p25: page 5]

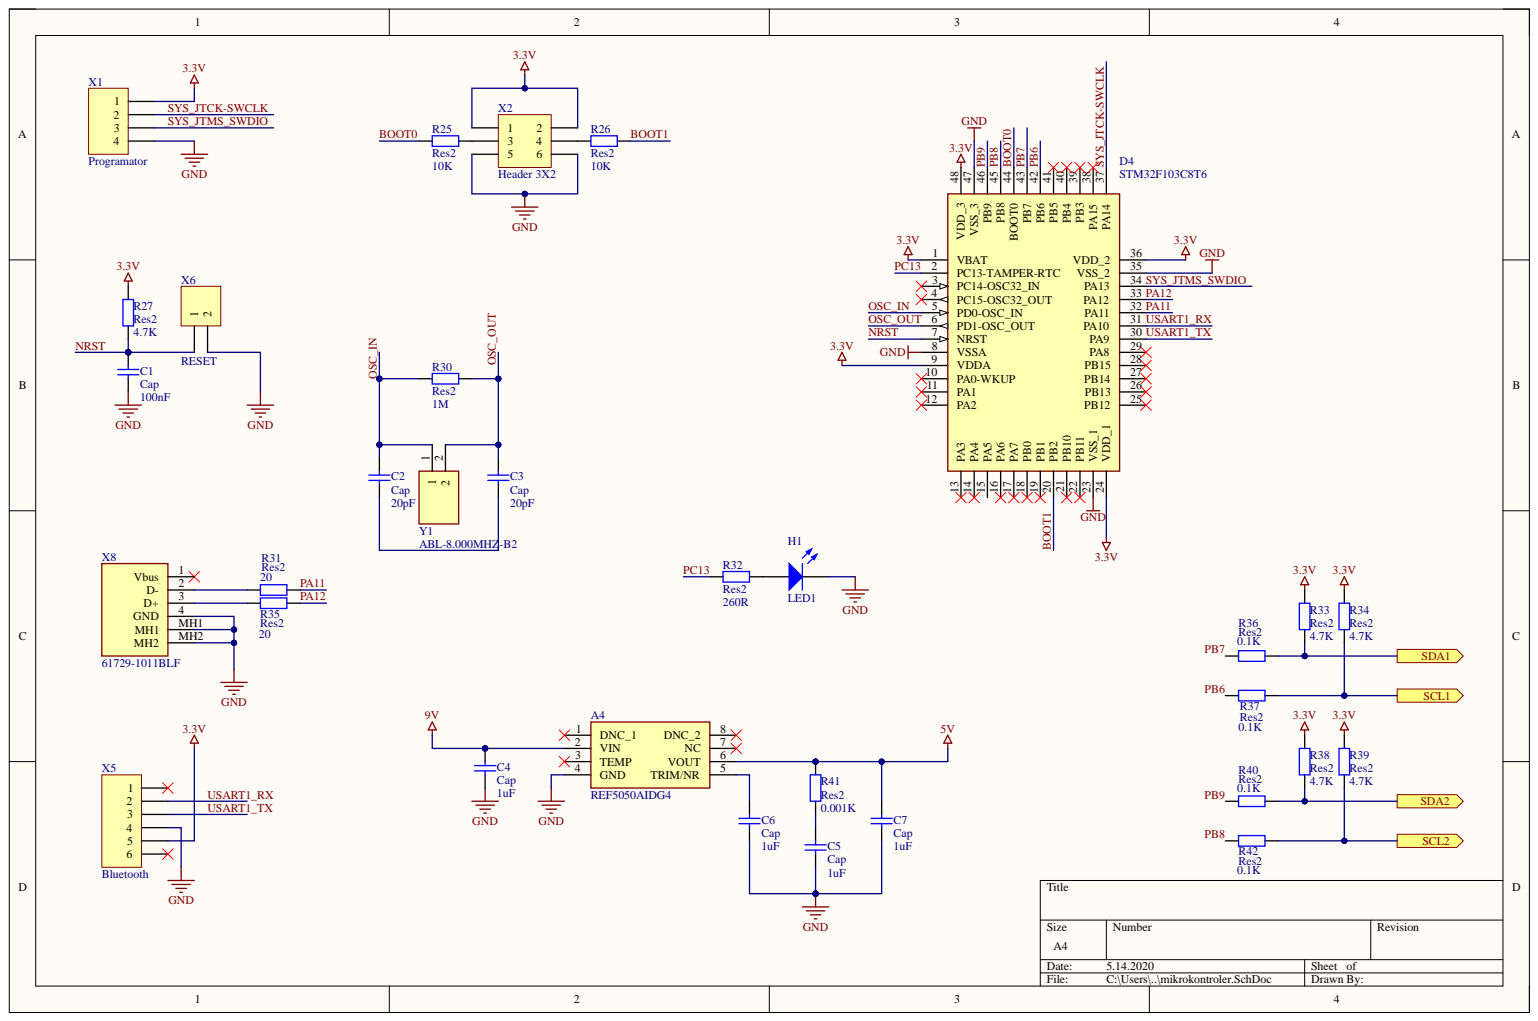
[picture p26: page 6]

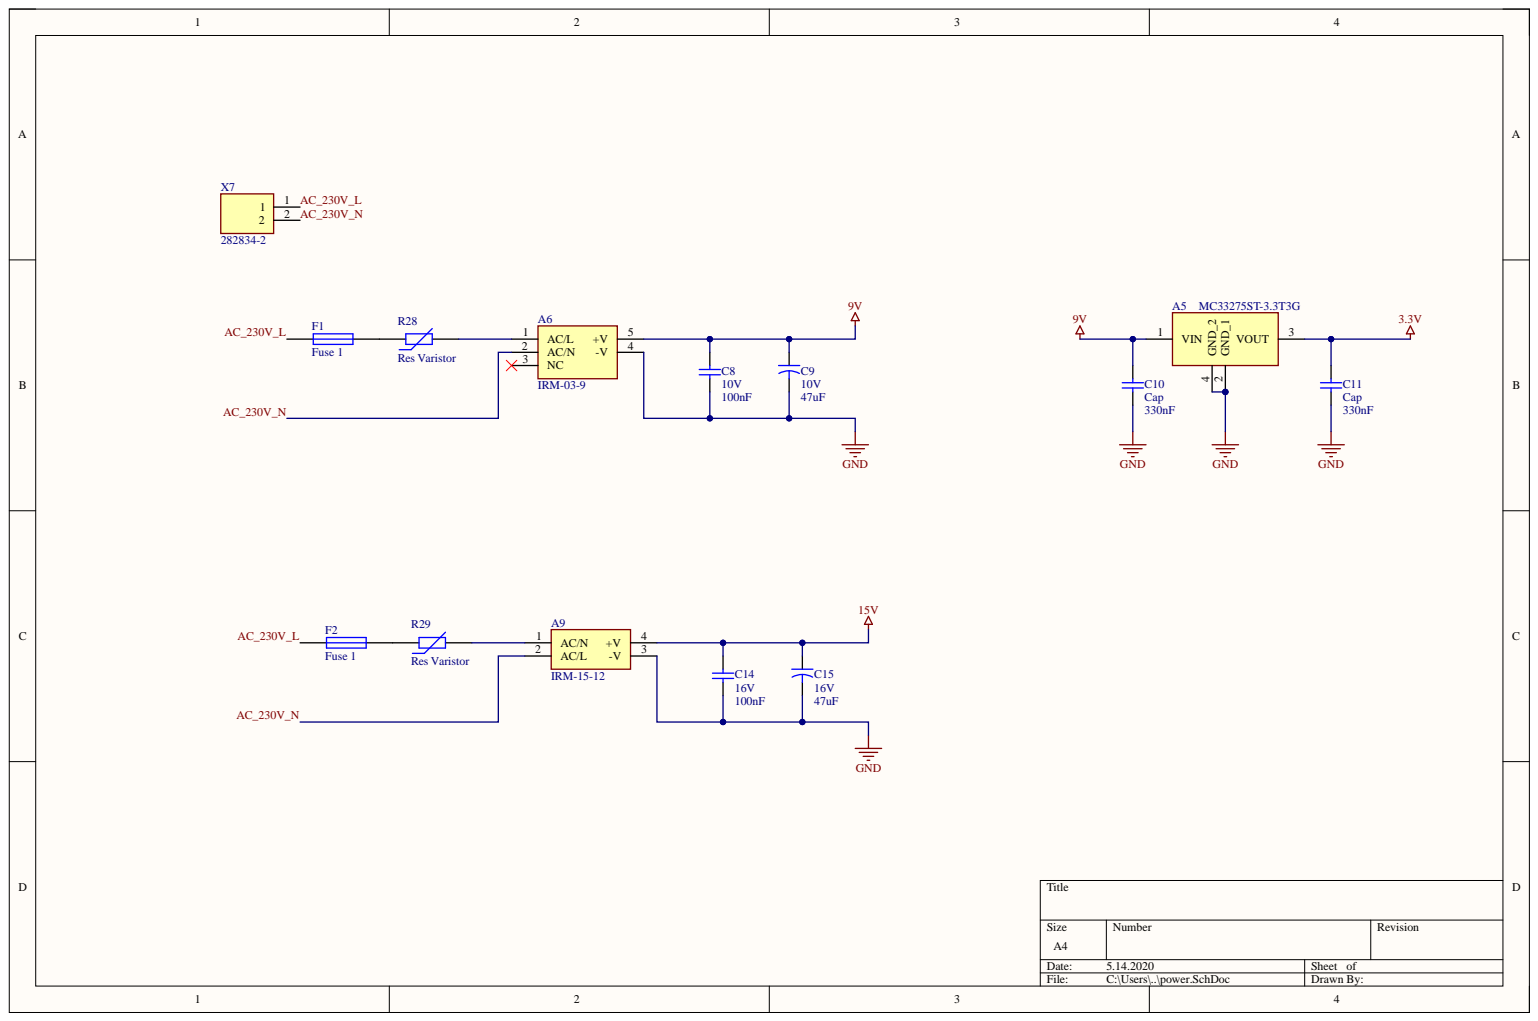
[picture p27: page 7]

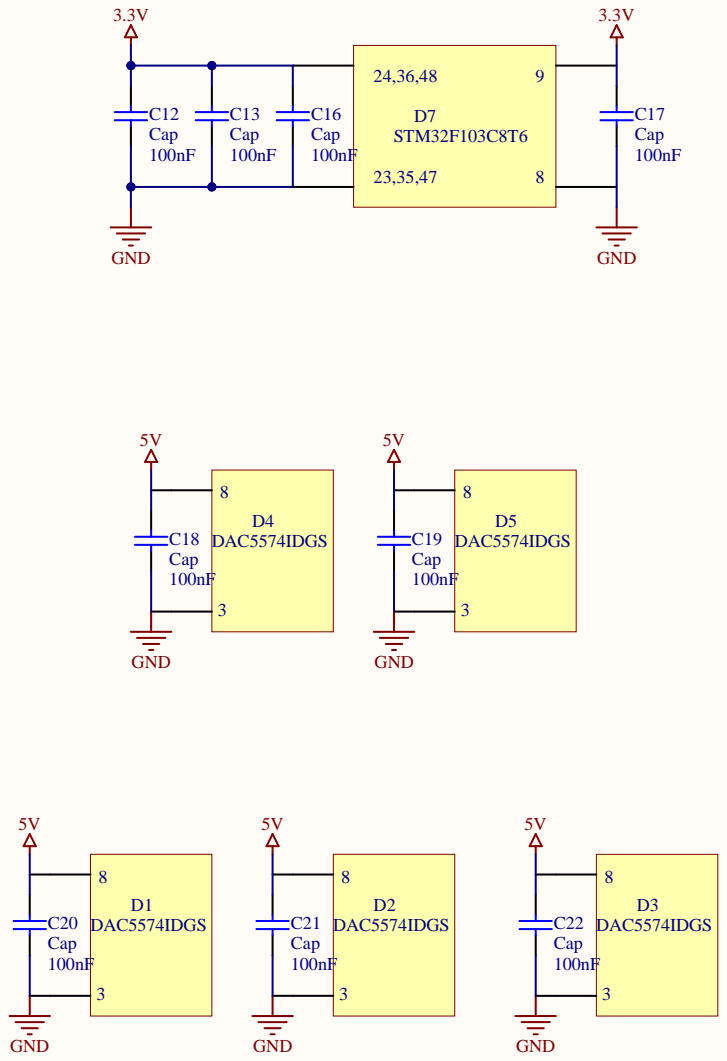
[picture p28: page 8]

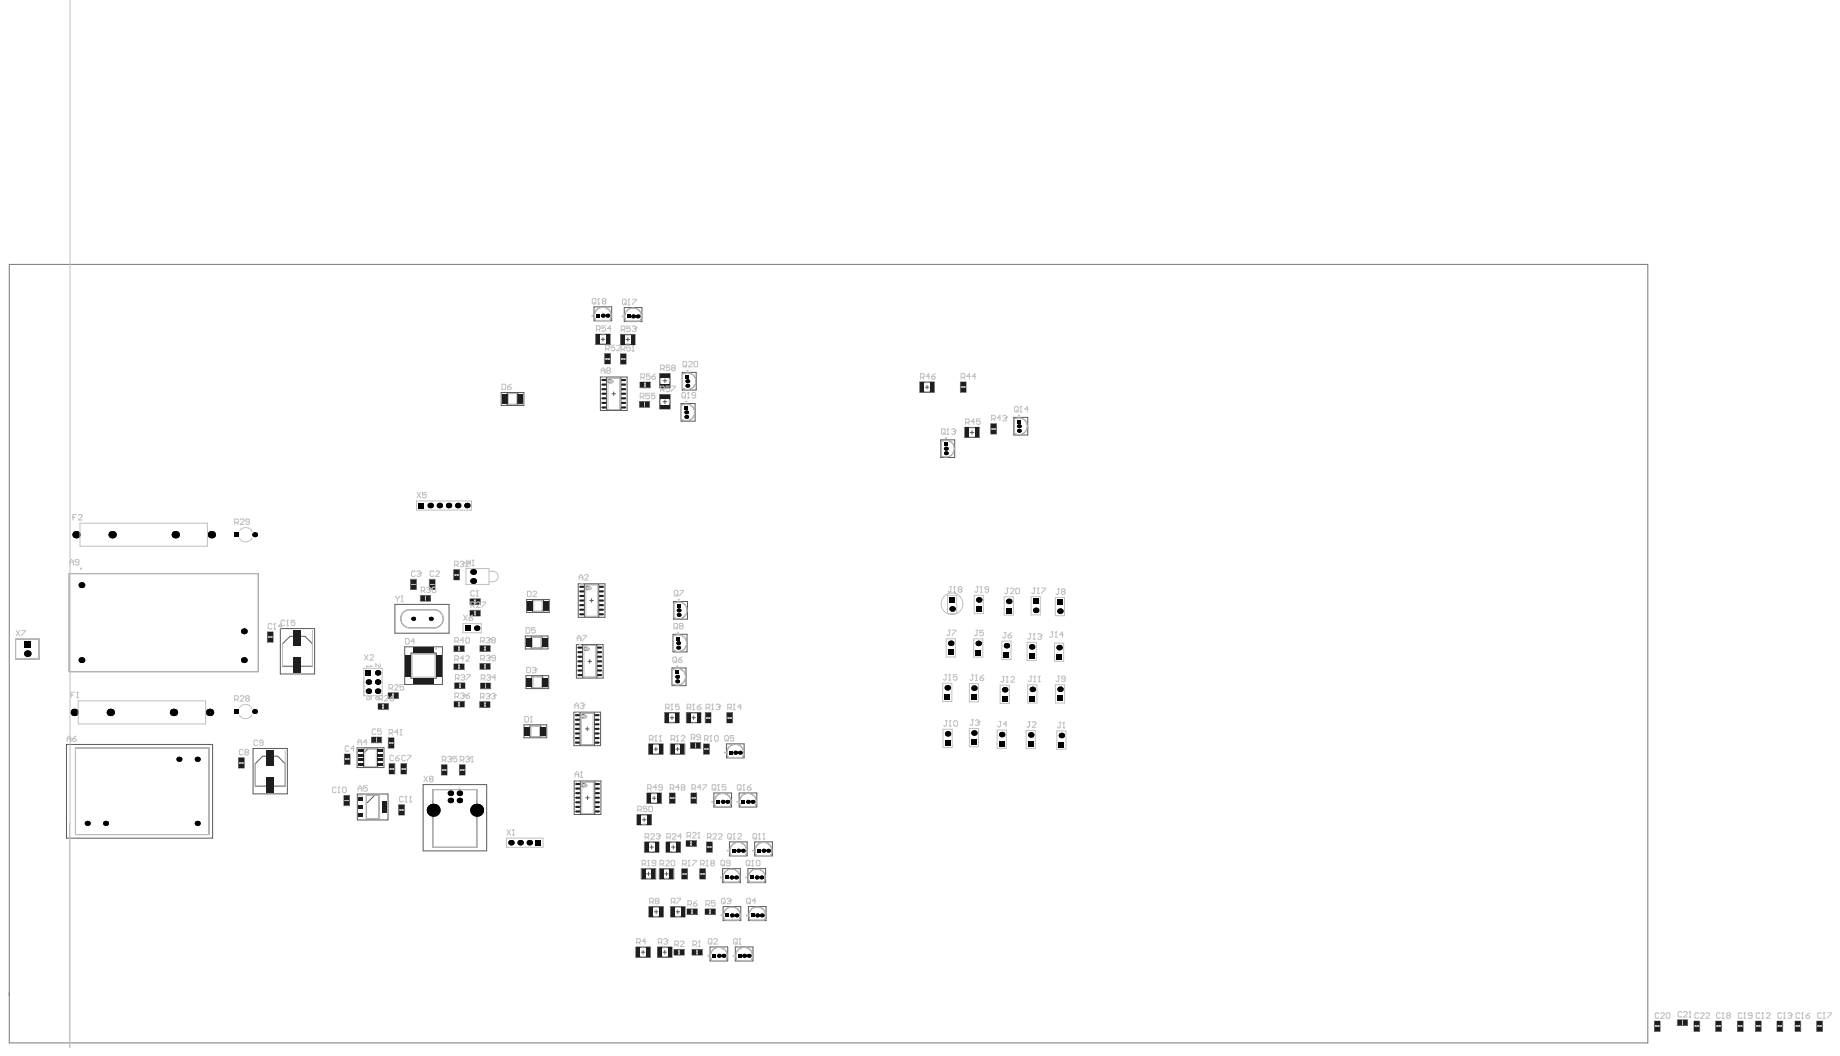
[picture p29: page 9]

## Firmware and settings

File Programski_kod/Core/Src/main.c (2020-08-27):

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

/* Includes ------------------------------------------------------------------*/
#include "main.h"
#include "i2c.h"
#include "usart.h"
#include "gpio.h"

/* USER CODE BEGIN Includes */
#include <string.h>
#include <math.h>
#include <ctype.h>

//#include "usbd_cdc_if.h"

/* USER CODE END Includes */

/* USER CODE BEGIN PD */

#define USER_TEST

#define VALID_COMMAND_LENGTH 10

#define I2C_ADDR_D6 (0b01001100)
#define I2C_ADDR_D5 (0b01001100)
#define I2C_ADDR_D3 (0b01001111)
#define I2C_ADDR_D2 (0b01001101)
#define I2C_ADDR_D1 (0b01001110)

#define I2C_CTRL_A (0b00010000)
#define I2C_CTRL_B (0b00010010)
#define I2C_CTRL_C (0b00010100)
#define I2C_CTRL_D (0b00010110)

#define I2C_PORT_1 (&hi2c1)
#define I2C_PORT_2 (&hi2c2)

/* USER CODE END PD */


/* USER CODE BEGIN PV */
volatile uint8_t command_buffer[50] = { '0', '0', '0', '0', '0', '0', '0', '0',
		'0', '0' };
volatile int command_buffer_pointer = 0;
volatile int command_received = 0;

/* USER CODE END PV */

void SystemClock_Config(void);
/* USER CODE BEGIN PFP */
void STATUS_LED_On(void);
void STATUS_LED_Off(void);
void STATUS_LED_Toggle(void);
int Command_Callback(uint8_t *cmd_in, uint32_t length);
void HAL_UART_RxCpltCallback(UART_HandleTypeDef *huart);

/* USER CODE END PFP */

/**
 * @brief  The application entry point.
 * @retval int
 */
int main(void) {
	/* USER CODE BEGIN 1 */
	STATUS_LED_Off();

	/* USER CODE END 1 */

	/* MCU Configuration--------------------------------------------------------*/

	/* Reset of all peripherals, Initializes the Flash interface and the Systick. */
	HAL_Init();

	/* USER CODE BEGIN Init */
	HAL_Delay(100);

	/* USER CODE END Init */

	/* Configure the system clock */
	SystemClock_Config();

	/* Initialize all configured peripherals */
	MX_GPIO_Init();
	MX_I2C1_Init();
	MX_I2C2_Init();
	MX_USART1_UART_Init();
	/* USER CODE BEGIN 2 */

	HAL_UART_Receive_IT(&huart1, command_buffer, 1);

	/* Signal to show we're online */
	STATUS_LED_On();

	/* USER CODE END 2 */

	/* Infinite loop */
	/* USER CODE BEGIN WHILE */

	/* ENABLE INTERRUPTS */
	__enable_irq();

	uint8_t num, val;
	uint8_t str[] = "LED_00_000";
	uint8_t matrix[4][5] = {{000, 127, 000, 127, 000},
													{127, 000, 127, 000, 127},
													{000, 127, 000, 127, 000},
													{127, 000, 127, 000, 127}};

	int i, j;

#ifdef USER_TEST
	/* init leds */
	for (i = 0; i < 20; i++) {
		str[4] = i / 10 + '0';
		str[5] = (i % 10) + '0';

		Command_Callback(str, 10);
	}
#endif /* USER_TEST */

	while (1) {
		/* USER CODE END WHILE */

		/* USER CODE BEGIN 3 */
#ifdef USER_TEST
		while (1) {
			for (i = 0; i < 20; i++) {
				str[4] = i / 10 + '0';
				str[5] = (i % 10) + '0';

				for (j = 0; j < 100; j++) {
					str[7] = (j / 100) + '0';
					str[8] = (j % 100 / 10) + '0';
					str[9] = (j % 10) + '0';

					HAL_Delay(4);

					Command_Callback(str, 10);
				}

				for (j = 100; j >= 0; j--) {
					str[7] = (j / 100) + '0';
					str[8] = (j % 100 / 10) + '0';
					str[9] = (j % 10) + '0';

					HAL_Delay(4);

					Command_Callback(str, 10);
				}
			}
		}
	}
#endif /* USER_TEST */

	/* Check if command was received */
	if (command_received) {
		Command_Callback(command_buffer, command_buffer_pointer);

		/* reset the flag */
		command_received = 0;

		/* reset the buffer */
		command_buffer_pointer = 0;
		memset(command_buffer, '0', VALID_COMMAND_LENGTH);
	}

/* USER CODE END 3 */
}

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
/* USER CODE BEGIN 4 */
/* Turn on Status LED */
void STATUS_LED_On(void) {
HAL_GPIO_WritePin(GPIOC, GPIO_PIN_13, GPIO_PIN_SET);

return;
}

/* Turn off Status LED */
void STATUS_LED_Off(void) {
HAL_GPIO_WritePin(GPIOC, GPIO_PIN_13, GPIO_PIN_RESET);

return;
}

/* Toggle Status LED */
void STATUS_LED_Toggle(void) {
HAL_GPIO_TogglePin(GPIOC, GPIO_PIN_13);

return;
}

/* Status LED blink Success */
void STATUS_LED_Blink_Success(void) {
/*
 STATUS_LED_Toggle();
 HAL_Delay(100);
 STATUS_LED_Toggle();
 HAL_Delay(100);
 STATUS_LED_Toggle();
 HAL_Delay(100);
 STATUS_LED_Toggle();
 HAL_Delay(100);
 */
}

/* Status LED blink Failure */
void STATUS_LED_Blink_Failure(void) {
/*
 STATUS_LED_Toggle();
 HAL_Delay(100);
 STATUS_LED_Toggle();
 HAL_Delay(100);
 STATUS_LED_Toggle();
 HAL_Delay(100);
 STATUS_LED_Toggle();
 HAL_Delay(100);
 STATUS_LED_Toggle();
 HAL_Delay(100);
 STATUS_LED_Toggle();
 HAL_Delay(100);
 */

}

/* This Callback function is called when data from USB is received */
void CDC_ReceiveCallback_FS(uint8_t *Buf, uint32_t Len) {
/* Set the flag only if we recieved valid number of chars */
if (Len == VALID_COMMAND_LENGTH) {
	memcpy(command_buffer, Buf, Len);
	command_buffer_pointer = Len;
	command_received = 1;
}
}

void HAL_UART_RxCpltCallback(UART_HandleTypeDef *huart) {
if (huart->Instance == USART1) {
	command_buffer_pointer++;

	/* If the beginning of the command buffer is valid */
	if (command_buffer[0] == 'L') {
		/* Don't overrun buffer */
		if (command_buffer_pointer < VALID_COMMAND_LENGTH) {

			HAL_UART_Receive_IT(huart, command_buffer + command_buffer_pointer, 1);

			/* If the buffer is full */
		} else {
			/* set the flag */
			command_received = 1;

			HAL_UART_Receive_IT(huart, command_buffer, 1);
		}
		/* if the beginning of the command buffer is invalid */
	} else {
		/* clear the buffer */
		command_buffer_pointer = 0;
		HAL_UART_Receive_IT(huart, command_buffer, 1);
	}
}

return;
}

int Command_extract_info(uint8_t *string, uint32_t length, uint32_t *led_id,
	uint32_t *led_val) {
if (length < 10) {
	return -1; /* Failure: command too short */
}

/* Check if command has defined structure */
if (string[0] != 'L'||
string[1] != 'E' ||
string[2] != 'D' ||
string[3] != '_' ||
! isdigit(string[4]) ||
! isdigit(string[5]) ||
string[6] != '_' ||
! isdigit(string[7]) ||
! isdigit(string[8]) ||
! isdigit(string[9])
) {

	return -1; /* Failure: wrong command */
}

/* String to led id (int) */
*led_id = (string[4] - '0') * 10 + (string[5] - '0');

/* String to led current (int)*/
*led_val = 100 * (string[7] - '0') + 10 * (string[8] - '0')
		+ 1 * (string[9] - '0');

/* Set upper bound on LED current value */
if (*led_val > 255) {
	*led_val = 255;
}

/* Set upper bound on LEDs */
if (*led_id >= 20) {

	return -1; /* Failure: not so many LEDs available */
}

/* return Success */
return 0;
}

int Command_Callback(uint8_t *cmd_in, uint32_t length) {
uint32_t led_id;
uint32_t led_val;
uint8_t dac_data[3];

/* Command format = LED_XX_ZZZ */

if (Command_extract_info(cmd_in, length, &led_id, &led_val) != 0) {
	/* Failure: can't extract led_id and led_val from input command */
	STATUS_LED_Blink_Failure();
	return -1;
}

/* DAC data setup */
dac_data[0] = 0b00010000; /* control byte */
dac_data[1] = led_val; /* msb byte */
dac_data[2] = 0b00000000; /* lsb byte (dont care byte) */

/* Based on LED Id send command to certain DAC (one of four available) */
switch (led_id) {
case 0:
	dac_data[0] = I2C_CTRL_B;
	HAL_I2C_Master_Transmit(I2C_PORT_1, I2C_ADDR_D6 << 1, dac_data, 3, 100);
	break;
case 1:
	dac_data[0] = I2C_CTRL_C;
	HAL_I2C_Master_Transmit(I2C_PORT_1, I2C_ADDR_D6 << 1, dac_data, 3, 100);
	break;
case 2:
	dac_data[0] = I2C_CTRL_D;
	HAL_I2C_Master_Transmit(I2C_PORT_1, I2C_ADDR_D6 << 1, dac_data, 3, 100);
	break;
case 3:
	dac_data[0] = I2C_CTRL_A;
	HAL_I2C_Master_Transmit(I2C_PORT_1, I2C_ADDR_D6 << 1, dac_data, 3, 100);
	break;
case 4:
	dac_data[0] = I2C_CTRL_A;
	HAL_I2C_Master_Transmit(I2C_PORT_2, I2C_ADDR_D2 << 1, dac_data, 3, 100);
	break;
case 5:
	dac_data[0] = I2C_CTRL_C;
	HAL_I2C_Master_Transmit(I2C_PORT_2, I2C_ADDR_D2 << 1, dac_data, 3, 100);
	break;
case 6:
	dac_data[0] = I2C_CTRL_D;
	HAL_I2C_Master_Transmit(I2C_PORT_2, I2C_ADDR_D2 << 1, dac_data, 3, 100);
	break;
case 7:
	dac_data[0] = I2C_CTRL_A;
	HAL_I2C_Master_Transmit(I2C_PORT_2, I2C_ADDR_D5 << 1, dac_data, 3, 100);
	break;
case 8:
	dac_data[0] = I2C_CTRL_B;
	HAL_I2C_Master_Transmit(I2C_PORT_2, I2C_ADDR_D2 << 1, dac_data, 3, 100);
	break;
case 9:
	dac_data[0] = I2C_CTRL_B;
	HAL_I2C_Master_Transmit(I2C_PORT_2, I2C_ADDR_D5 << 1, dac_data, 3, 100);
	break;
case 10:
	dac_data[0] = I2C_CTRL_A;
	HAL_I2C_Master_Transmit(I2C_PORT_2, I2C_ADDR_D3 << 1, dac_data, 3, 100);
	break;
case 11:
	dac_data[0] = I2C_CTRL_D;
	HAL_I2C_Master_Transmit(I2C_PORT_2, I2C_ADDR_D3 << 1, dac_data, 3, 100);
	break;
case 12:
	dac_data[0] = I2C_CTRL_C;
	HAL_I2C_Master_Transmit(I2C_PORT_2, I2C_ADDR_D3 << 1, dac_data, 3, 100);
	break;
case 13:
	dac_data[0] = I2C_CTRL_C;
	HAL_I2C_Master_Transmit(I2C_PORT_2, I2C_ADDR_D5 << 1, dac_data, 3, 100);
	break;
case 14:
	dac_data[0] = I2C_CTRL_D;
	HAL_I2C_Master_Transmit(I2C_PORT_2, I2C_ADDR_D5 << 1, dac_data, 3, 100);
	break;
case 15:
	dac_data[0] = I2C_CTRL_B;
	HAL_I2C_Master_Transmit(I2C_PORT_2, I2C_ADDR_D3 << 1, dac_data, 3, 100);
	break;
case 16:
	dac_data[0] = I2C_CTRL_A;
	HAL_I2C_Master_Transmit(I2C_PORT_2, I2C_ADDR_D1 << 1, dac_data, 3, 100);
	break;
case 17:
	dac_data[0] = I2C_CTRL_D;
	HAL_I2C_Master_Transmit(I2C_PORT_2, I2C_ADDR_D1 << 1, dac_data, 3, 100);
	break;
case 18:
	dac_data[0] = I2C_CTRL_C;
	HAL_I2C_Master_Transmit(I2C_PORT_2, I2C_ADDR_D1 << 1, dac_data, 3, 100);
	break;
case 19:
	dac_data[0] = I2C_CTRL_B;
	HAL_I2C_Master_Transmit(I2C_PORT_2, I2C_ADDR_D1 << 1, dac_data, 3, 100);
	break;
}

/* Return Success */
STATUS_LED_Blink_Success();
return 0;
}

/* USER CODE END 4 */
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


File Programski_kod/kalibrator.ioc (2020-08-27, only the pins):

Mcu.UserName=STM32F103C8Tx
PA10.Signal=USART1_RX
PA13.Signal=SYS_JTMS-SWDIO
PA14.Signal=SYS_JTCK-SWCLK
PA9.Signal=USART1_TX
PB10.Signal=I2C2_SCL
PB11.Signal=I2C2_SDA
PB6.Signal=GPIO_Input
PB7.Signal=GPIO_Input
PB8.Signal=I2C1_SCL
PB9.Signal=I2C1_SDA
PC13-TAMPER-RTC.Signal=GPIO_Output
PD0-OSC_IN.Signal=RCC_OSC_IN
PD1-OSC_OUT.Signal=RCC_OSC_OUT

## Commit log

2020-03-26 Status Ledica, USB TX
2020-03-26 USB RX Working
    Both USB RX and TX are working now. Next should be UART for Bluetooth.
2020-04-25 Dodani footprinti za fusove i varistore
    [Klaibracija2.PcbLib, mikrokontroler.SchDoc, power.SchDoc]
2020-05-06 ...
    ...
    [Plocica_kalibrator.PcbDoc, SamacSys2.PcbLib, SamacSys2.SchLib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]
2020-05-12 pocetak plocice
    [Plocica_kalibrator.PcbDoc, SamacSys2.PcbLib, SamacSys2.SchLib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]
2020-05-17 plocica
    .
    [Plocica_kalibrator.PcbDoc]
2020-05-18 PLOCICA_NASTAVAK
    ..
    [Plocica_kalibrator.PcbDoc, blokadni_kondenzatori.SchDoc, led1.SchDoc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]
2020-05-29 plocica
    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
    [Plocica_kalibrator.PcbDoc, led1.SchDoc]
2020-06-03 ....
    ....
    [Plocica_kalibrator.PcbDoc]
2020-08-16 status led fix

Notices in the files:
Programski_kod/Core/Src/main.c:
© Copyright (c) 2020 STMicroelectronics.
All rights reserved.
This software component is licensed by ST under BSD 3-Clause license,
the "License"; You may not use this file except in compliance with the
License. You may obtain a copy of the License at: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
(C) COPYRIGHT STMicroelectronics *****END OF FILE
